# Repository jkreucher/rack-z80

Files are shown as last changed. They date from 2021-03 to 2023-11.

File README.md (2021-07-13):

# Rack Z80 Computer

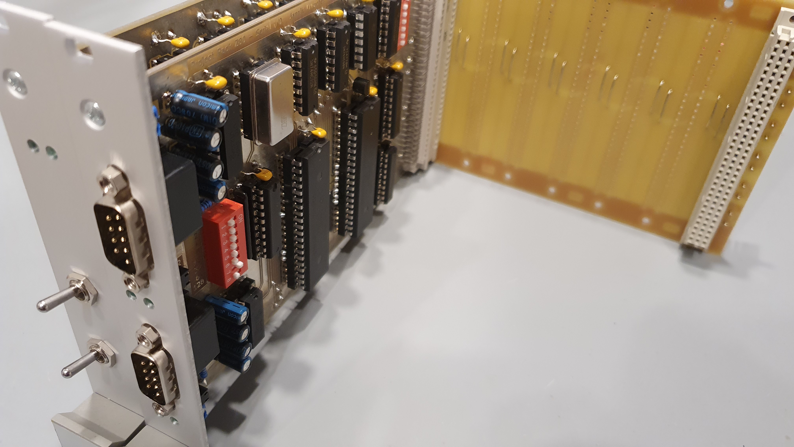
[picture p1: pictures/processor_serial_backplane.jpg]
PCB

Copyright 2021 Jannik Kreucher

**NOTE: This Project is still work in progress and not working at this point !**

## Table of Contents
 - [About The Project](#about-the-project)
 - [Folder Structure](#folder-structure)
 - [Modules](#modules)

## About The Project

The goal of this project is to understand how computers and operating systems work. This is a collection of hardware and software to create a multi purpose 8-Bit computer with the popular [ZiLog Z80](https://de.wikipedia.org/wiki/Zilog_Z80) processor as the heart of this project. Everything is contained in a [Eurocard Subrack](https://en.wikipedia.org/wiki/Eurocard_(printed_circuit_board)) formfactor because I really like the industrial look to it. This makes it really flexible and easy to expand (and good looking of course). All the parts used should still be manufacured and every PCB is etched at home so everyone can reproduce this project. I know chinese PCB houses are fairly cheap these days but I love tinkering and I have the PCB right away and dont need to wait 2 weeks for the next revision because it seems like the first design is never working.

## Folder Structure

The project is divided into following directories:
 - code
 - schematics
 - tools

[`schematics/`](schematics) contains all the PCBs I designed for this project. Each board has its own README file for way more detailed information. [`code/`](code) contains the source code for the Z80 computer itself. The directory [`tools/`](tools) contains everything needed to compile, assemble source code and other software for this project.

## Modules
To get more information about one module click on the link.
 - [Processor Board](schematics/RackZ80_Processor)
 - [RS232 Serial Interface](schematics/RackZ80_RS232)

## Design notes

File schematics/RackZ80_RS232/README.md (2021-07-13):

# Serial I/O

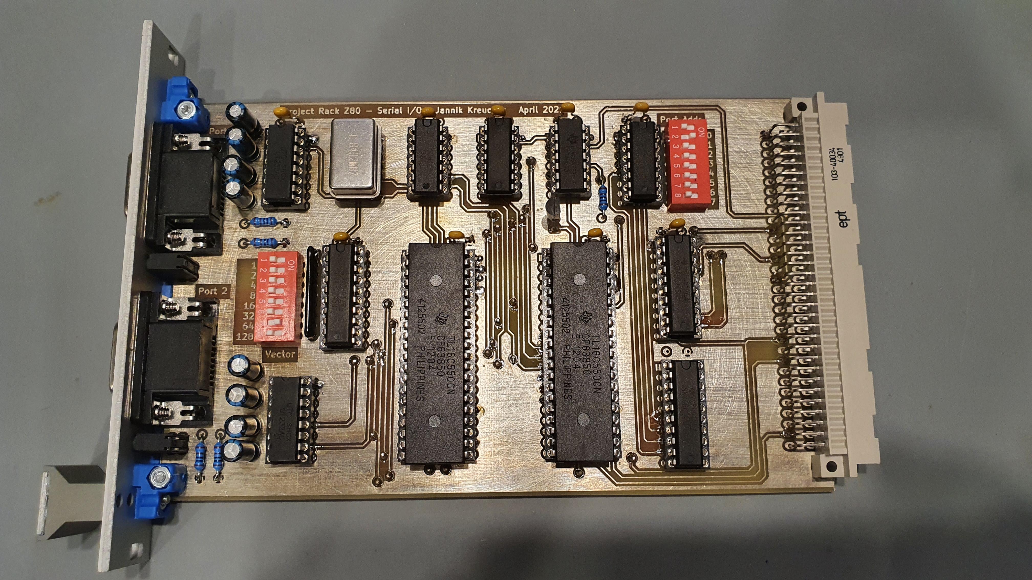
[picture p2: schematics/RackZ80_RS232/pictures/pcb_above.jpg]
PCB

Copyright 2021 Jannik Kreucher

## Table of Contents
 - [How it works](#how-it-works)
 - [Schematic](#schematic)

## How it works
TODO

## Schematic
The [schematic](documentation/RackZ80_RS232.pdf) exported as pdf. So it is ready to print.

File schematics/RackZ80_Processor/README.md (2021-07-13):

# Processor Board

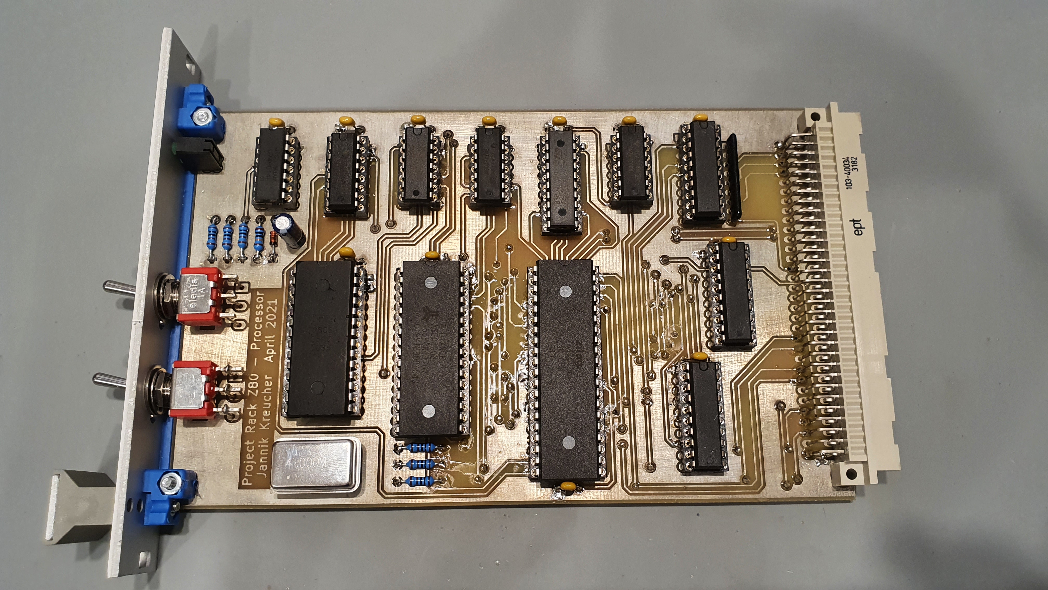
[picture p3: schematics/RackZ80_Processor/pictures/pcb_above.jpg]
PCB

Copyright 2021 Jannik Kreucher

## Table of Contents
 - [How it works](#how-it-works)
 - [Schematic](#schematic)

## How it works
TODO

## Schematic
The [schematic](documentation/RackZ80_Processor.pdf) exported as pdf. So it is ready to print.

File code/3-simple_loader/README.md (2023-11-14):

# Very Simple Loader
This projects aims to make development easier. Removing the EEPROM and programming it every time is very tedious and time consuming. With this project a very simple rom loader is implemented. A binary file can be transferred via UART and be executed by the RackZ80.

## Inner Workings
The CPU expects binary data in form of hex values in ascii on UART port 1. This data gets copied to RAM page 0 which will be placed in the lower 32k later. Once copied, a very simple programm is placed in the upper 32k in RAM page 1 which will replace the lower 32k ROM with the RAM page 0. Next the programm jumps to 0x0000.

Note: No error checking is implemented!

## Sending a Binary File
```
./send.sh ../1-uart_test/uart_echo.rom
```

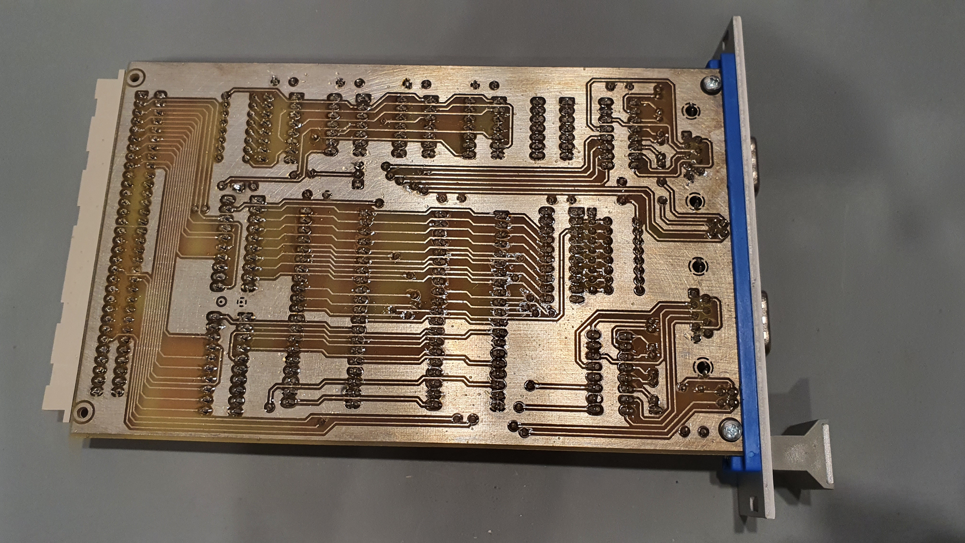
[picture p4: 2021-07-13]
schematics/RackZ80_RS232/pictures/pcb_below.jpg

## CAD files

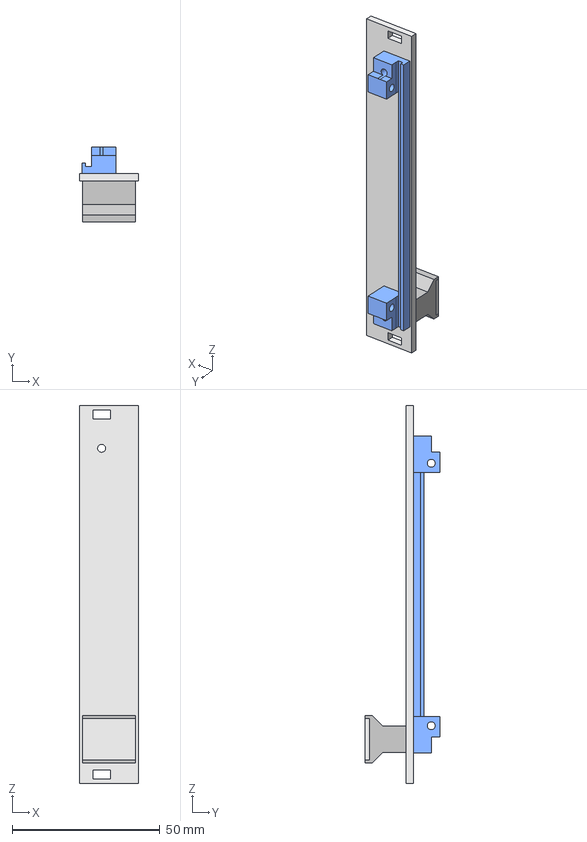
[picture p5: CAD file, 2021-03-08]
schematics/RackZ80_Backplane/rackz80_packages3d/Subrack4TE_FrontPanel.FCStd
20.0 x 25.5 x 128.0 mm
FrontPlate
Handle
NamePlate
PCBMountingSpacer

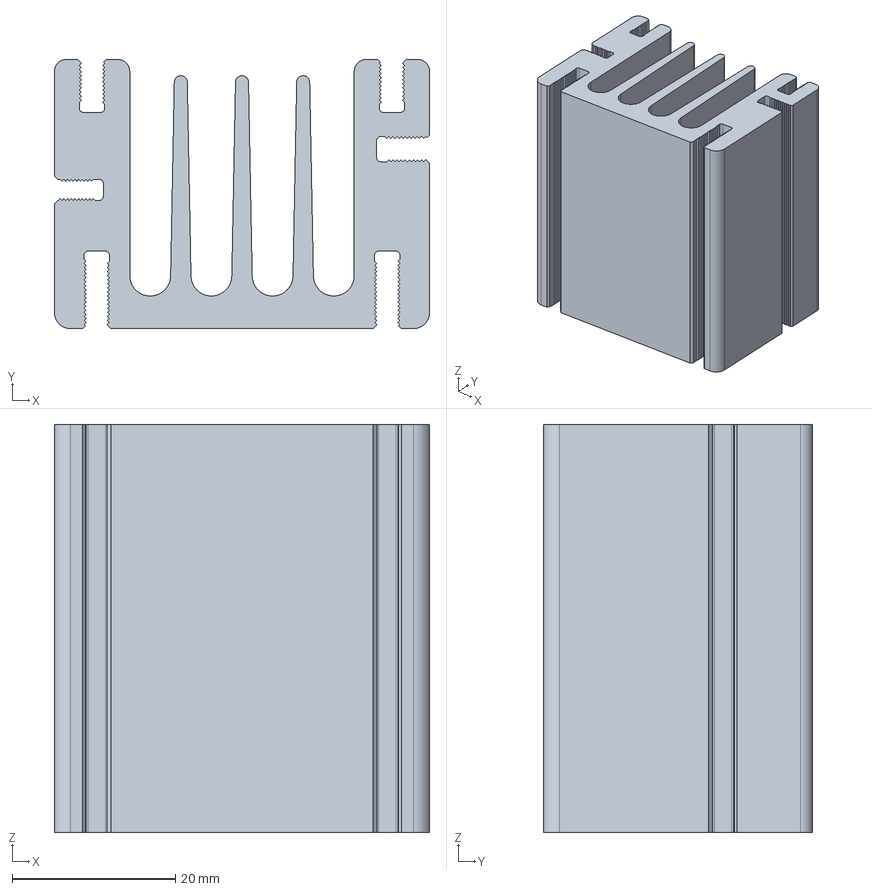
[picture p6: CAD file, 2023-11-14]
schematics/RackZ80_PowerSupply/3dmodels/Fischer_Heatsink_SK68_50mm.step
46.0 x 33.0 x 50.0 mm

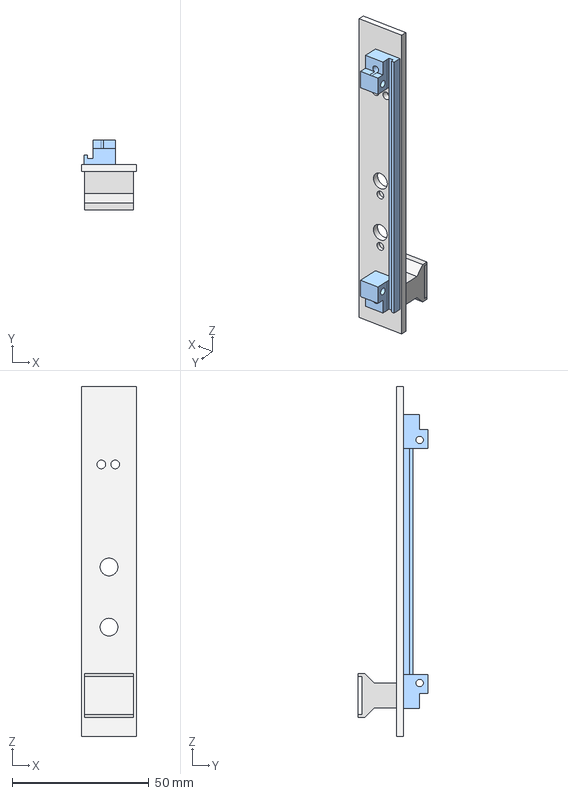
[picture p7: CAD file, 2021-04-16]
schematics/RackZ80_Processor/frontpanel/Subrack4TE_Processor_FrontPanel.step
20.0 x 25.5 x 128.0 mm
Handle
NamePlate
PCBMountingSpacer
ProcessorFrontPanel

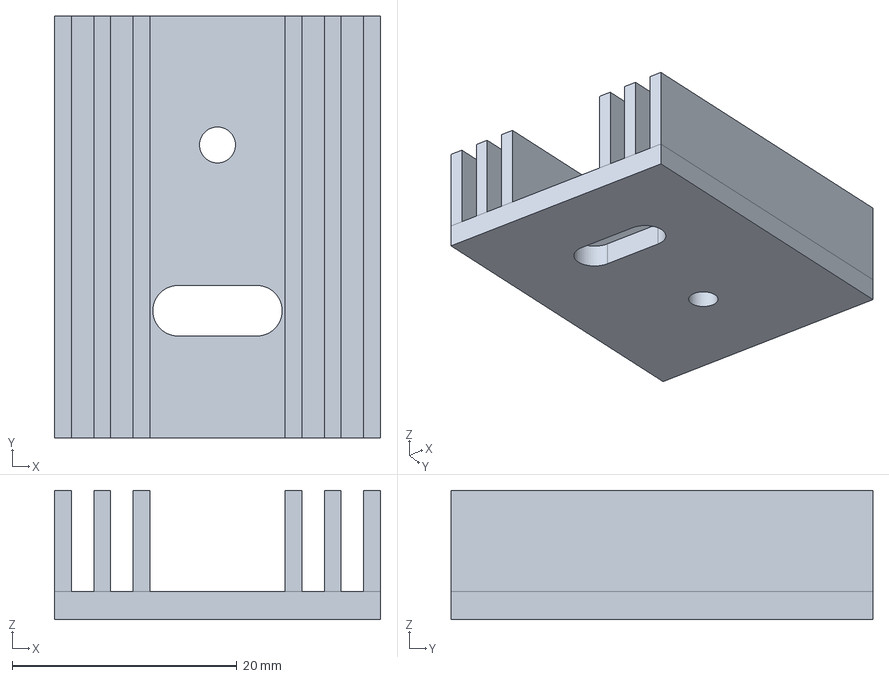
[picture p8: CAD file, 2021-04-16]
schematics/RackZ80_Processor/rackz80_packages3d/SK09_37.FCStd
29.0 x 37.5 x 11.5 mm

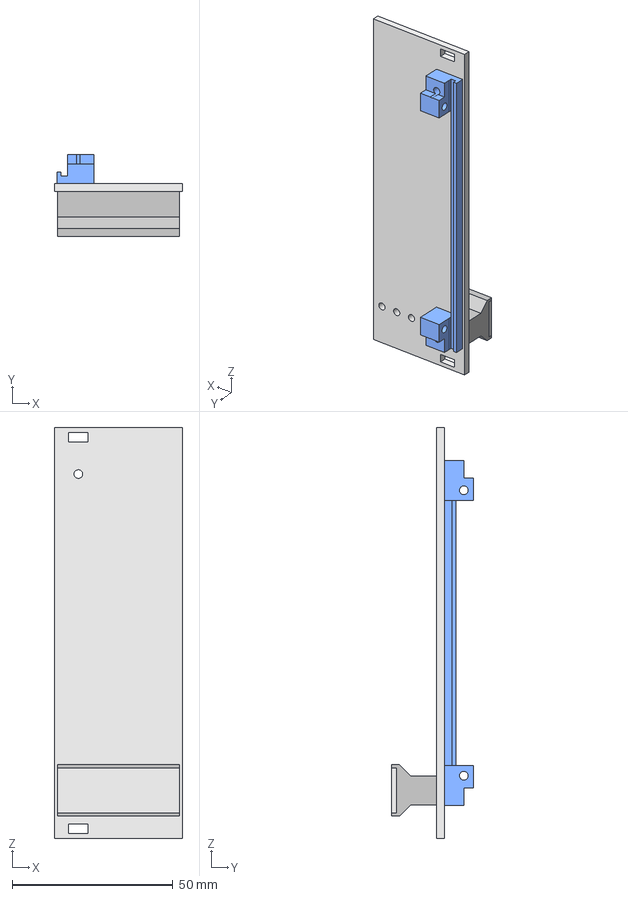
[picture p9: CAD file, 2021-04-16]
schematics/RackZ80_RS232/rackz80_packages3d/Subrack8TE_FrontPanel.FCStd
40.0 x 25.5 x 128.0 mm
FrontPlate
Handle
NamePlate
PCBMountingSpacer

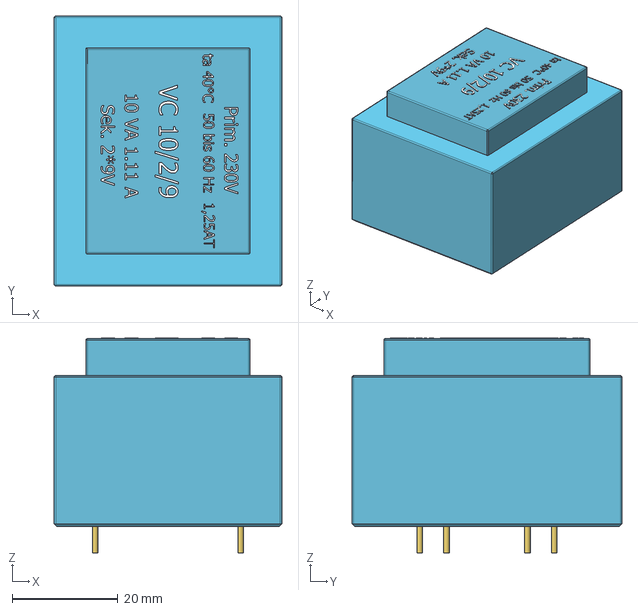
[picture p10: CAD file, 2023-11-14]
schematics/RackZ80_PowerSupply/3dmodels/BlockTrafo_VC10_10VA.step
43.0 x 51.0 x 40.6 mm

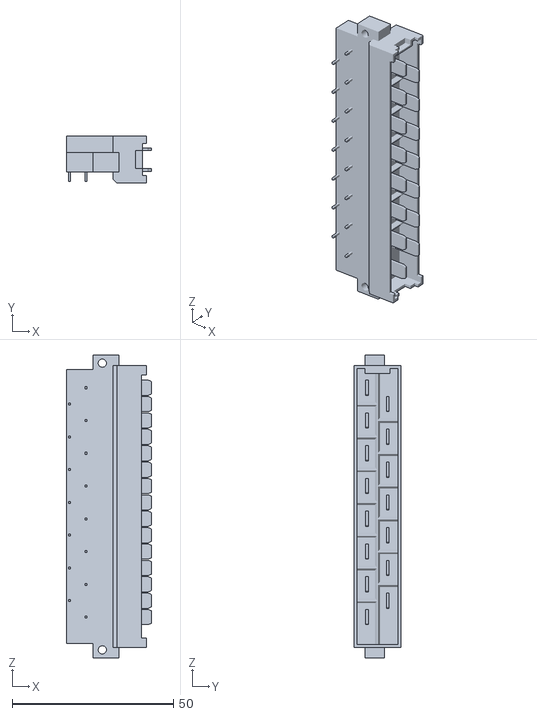
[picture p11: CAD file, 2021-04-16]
schematics/RackZ80_RS232/rackz80_packages3d/User Library-DIN41612-H-15-M-RA.stl
26.4 x 14.7 x 94.0

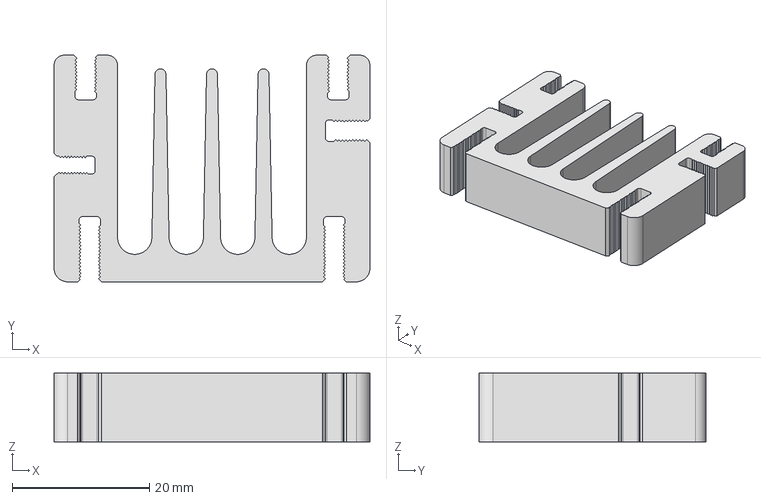
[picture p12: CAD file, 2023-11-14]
schematics/RackZ80_PowerSupply/3dmodels/Fischer_Heatsink_SK68.step
46.0 x 33.0 x 10.0 mm

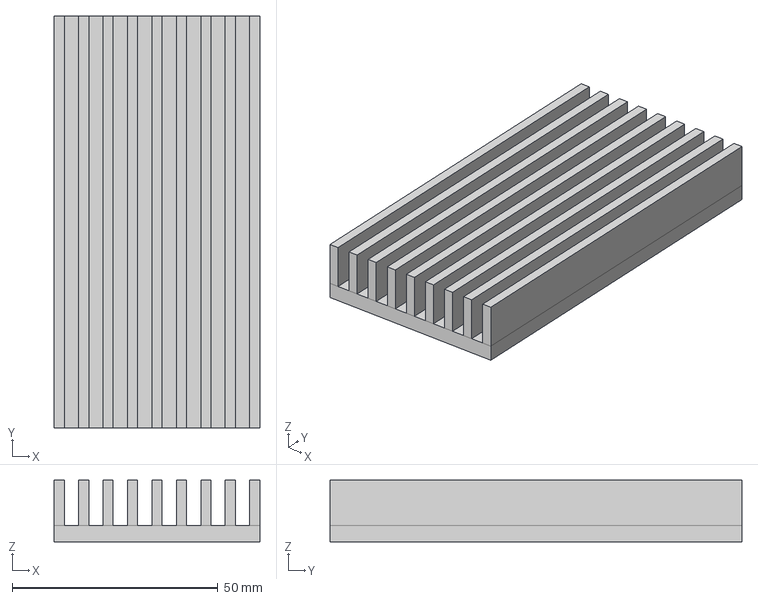
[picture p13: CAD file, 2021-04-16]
schematics/RackZ80_Processor/rackz80_packages3d/Heatsink_SK81_100_Cut.step
50.0 x 100.0 x 15.0 mm

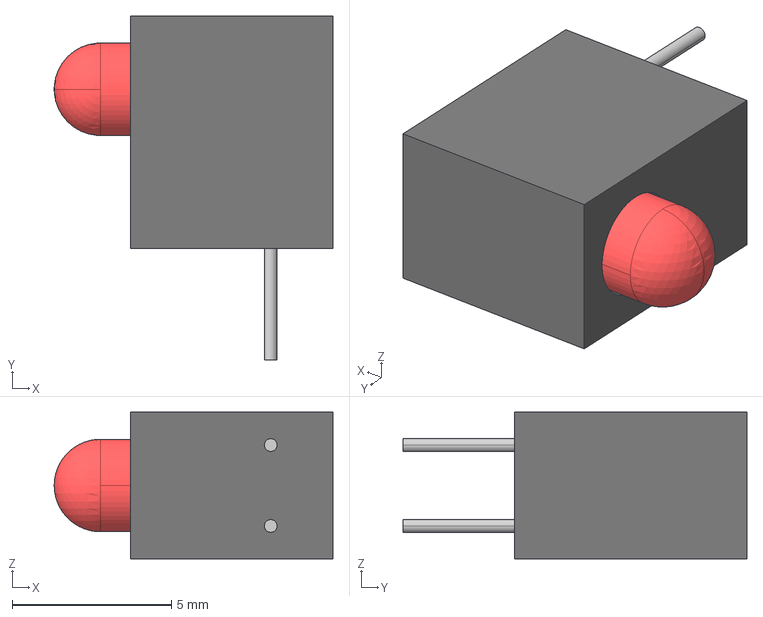
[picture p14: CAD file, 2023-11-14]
schematics/RackZ80_PowerSupply/3dmodels/LED_Kingbright_T-1_3mm_single.step
8.75 x 10.8 x 4.60 mm

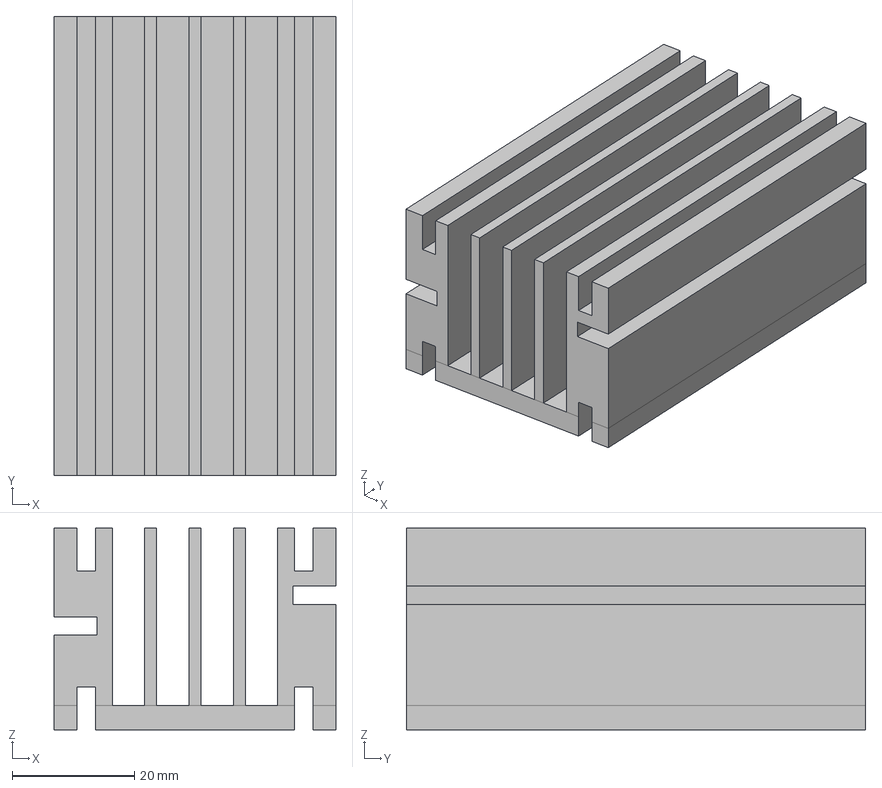
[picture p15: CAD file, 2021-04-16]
schematics/RackZ80_Processor/rackz80_packages3d/SK68_75mm.step
46.0 x 75.0 x 33.0 mm

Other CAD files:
schematics/RackZ80_RS232/frontpanel/Subrack4TE_Serial_FrontPanel.step
schematics/RackZ80_PowerSupply/3dmodels/Fischer_Heatsink_SK68_75mm.step
schematics/RackZ80_PowerSupply/3dmodels/DIN41612_H15_Male_90deg_ept.step
schematics/RackZ80_PowerSupply/3dmodels/Fischer_4TE.step
schematics/RackZ80_PowerSupply/3dmodels/Fischer_8TE.step
schematics/RackZ80_PowerSupply/3dmodels/LED_Kingbright_T-1_3mm_dual.step
schematics/RackZ80_Processor/frontpanel/Subrack4TE_Processor_FrontPanel.FCStd
schematics/RackZ80_Processor/rackz80_packages3d/DIN41612_H15.step
schematics/RackZ80_Processor/rackz80_packages3d/Heatsink_SK81_100_Cut.FCStd
schematics/RackZ80_Processor/rackz80_packages3d/SK09_37-SK09_37.step
schematics/RackZ80_Processor/rackz80_packages3d/SK68_75mm.FCStd
schematics/RackZ80_Processor/rackz80_packages3d/Transformer_30VA_2x12V.step
schematics/RackZ80_Processor/rackz80_packages3d/din41612_H15.step
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

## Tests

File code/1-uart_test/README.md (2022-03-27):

# First UART Test
First UART RX/TX test using vector interrupts. This test code sends characters back it receives using an interrupt. The goal of this simple code is to demonstrate that the cpu and uart boards are working including the Z80 vectored interrupt logic I implemented into the UART card.

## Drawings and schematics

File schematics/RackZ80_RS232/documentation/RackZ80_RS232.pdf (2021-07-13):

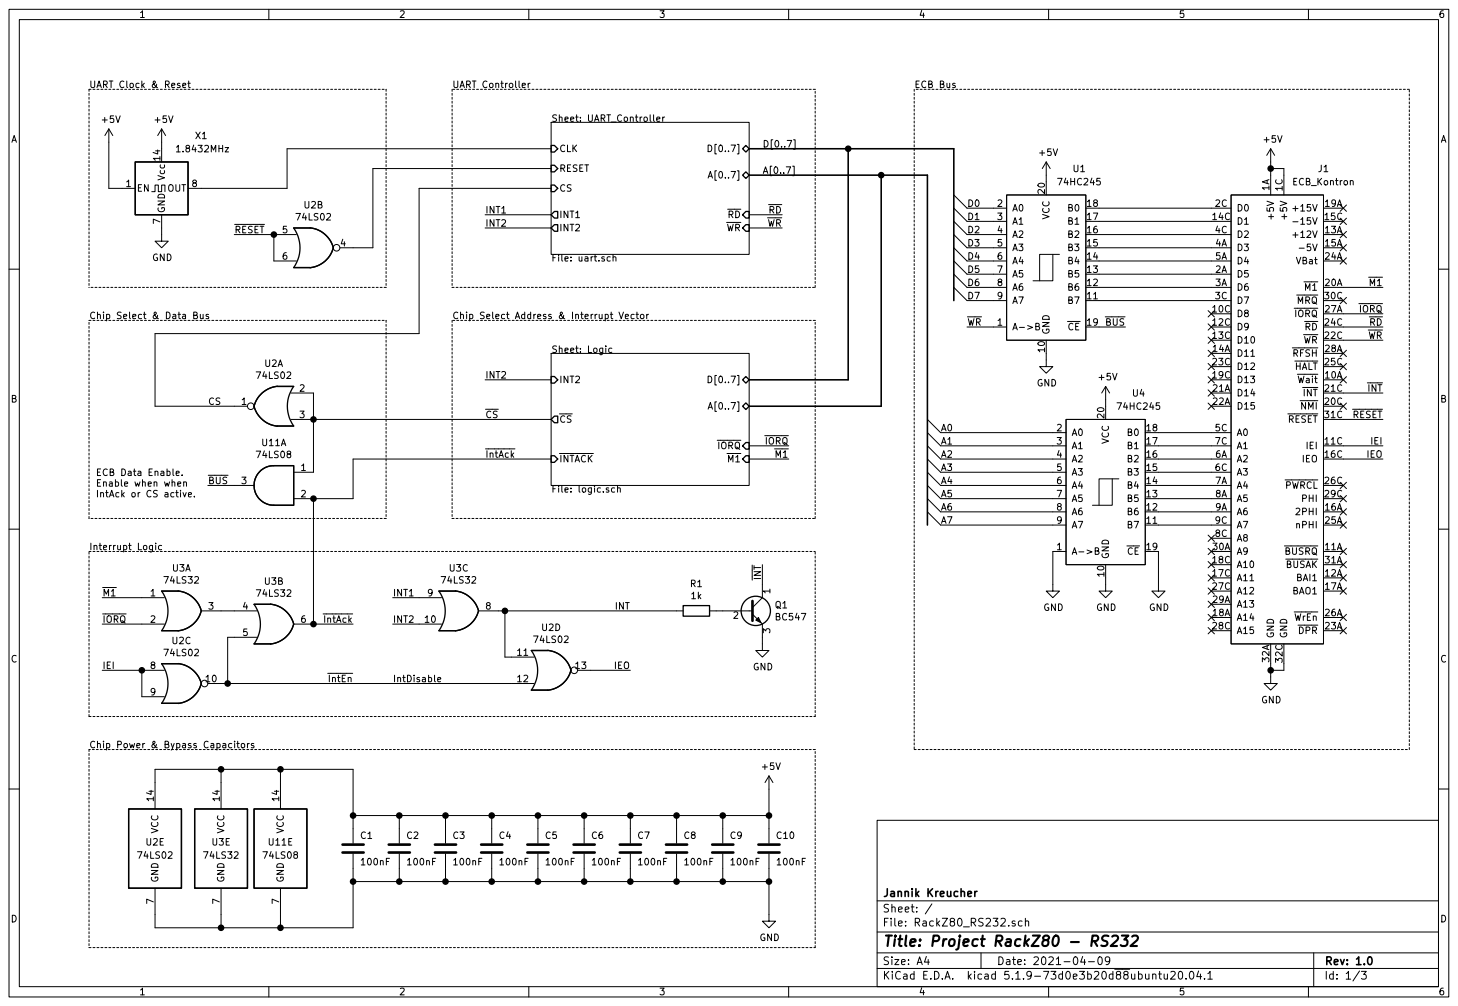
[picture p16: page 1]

IntAck or CS active.

Chip Power & Bypass Capacitors

File: RackZ80_RS232.sch Sheet: / Jannik Kreucher

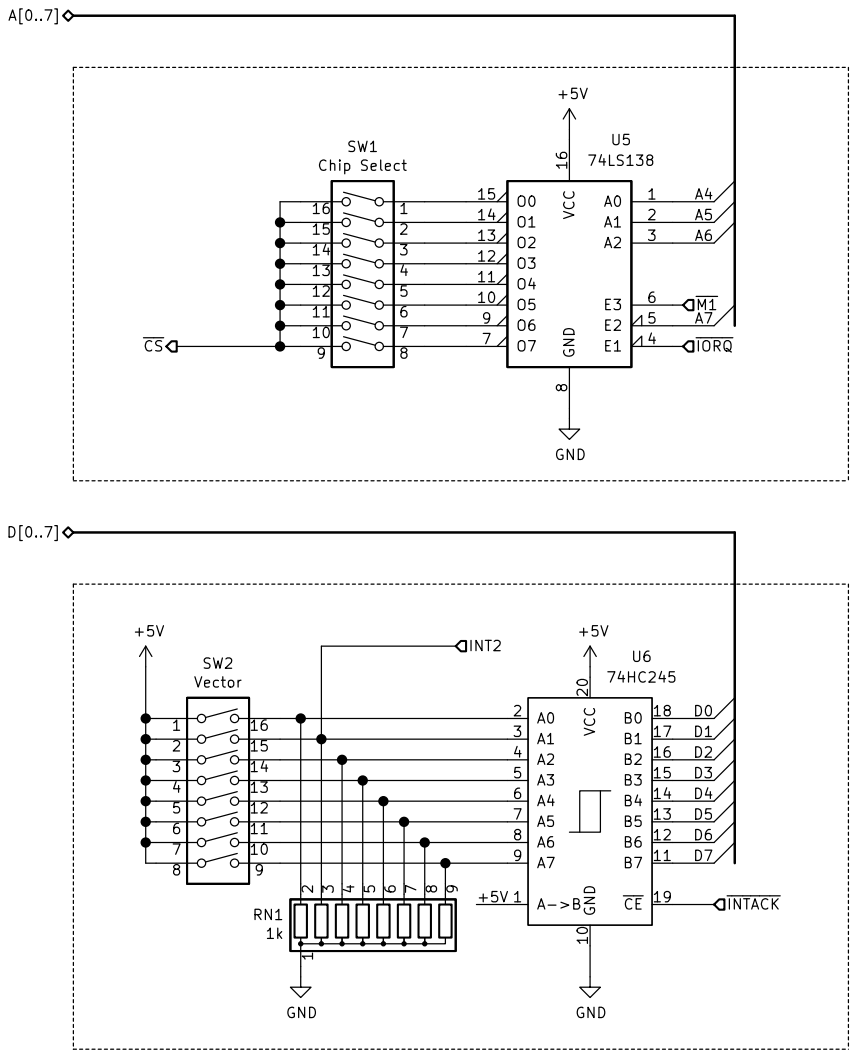
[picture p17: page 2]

16 | 1
15 | 2
14 | 3
13 | 4
12 | 5
11 | 6

16
15
14
13
12
11
10

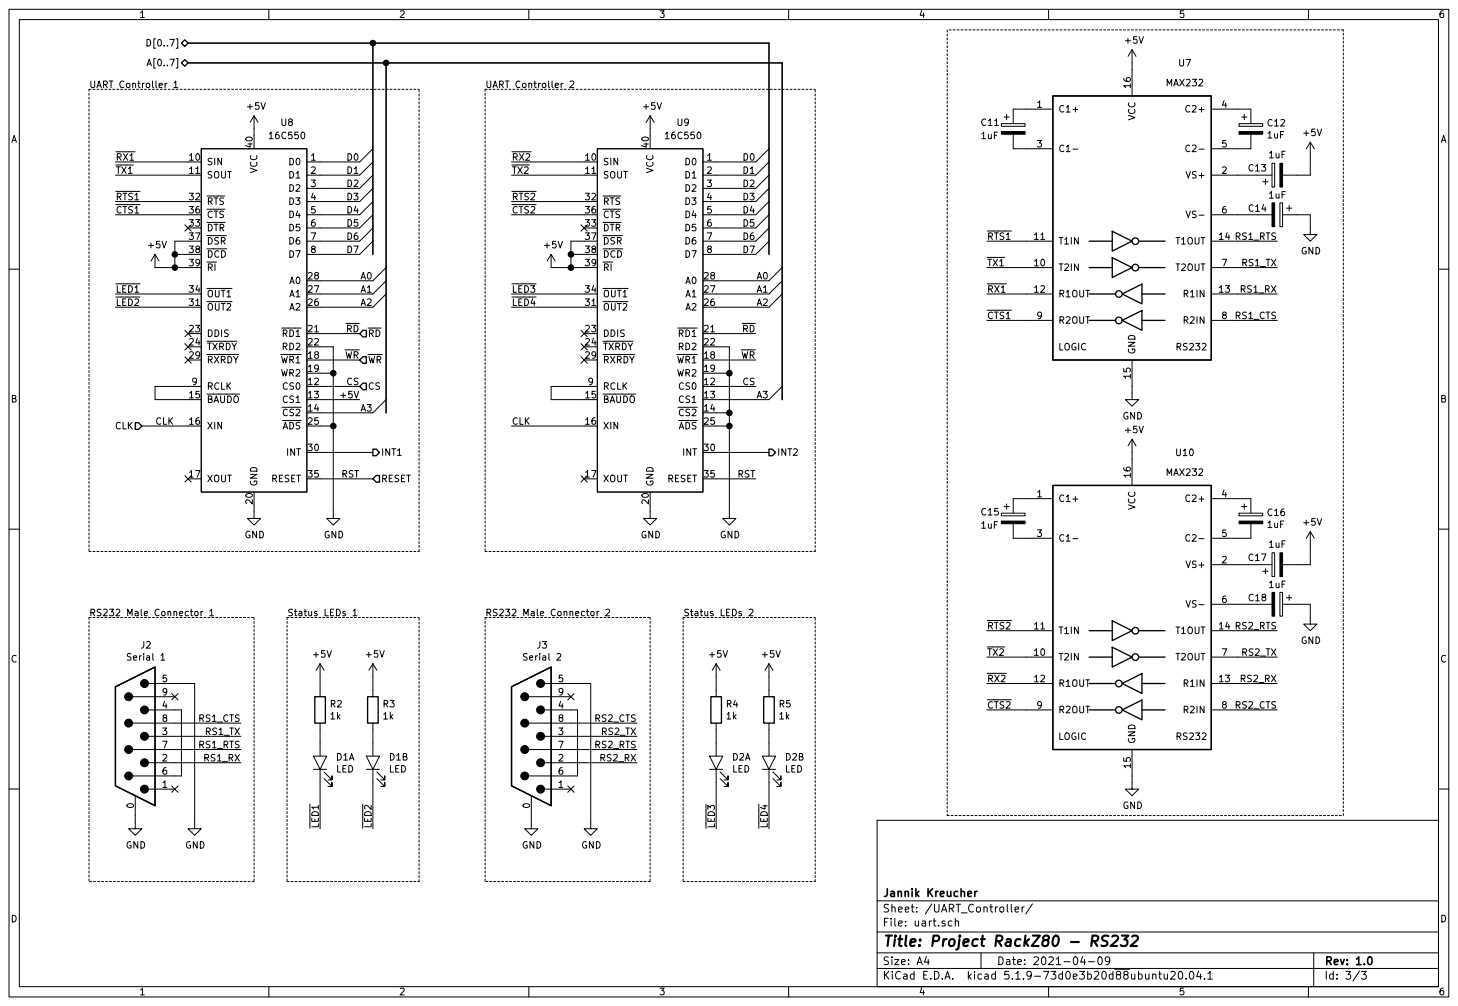
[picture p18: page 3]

UART Controller 2 RS232 Male Connector 2

File: uart.sch Sheet: /UART_Controller/ Jannik Kreucher D2B

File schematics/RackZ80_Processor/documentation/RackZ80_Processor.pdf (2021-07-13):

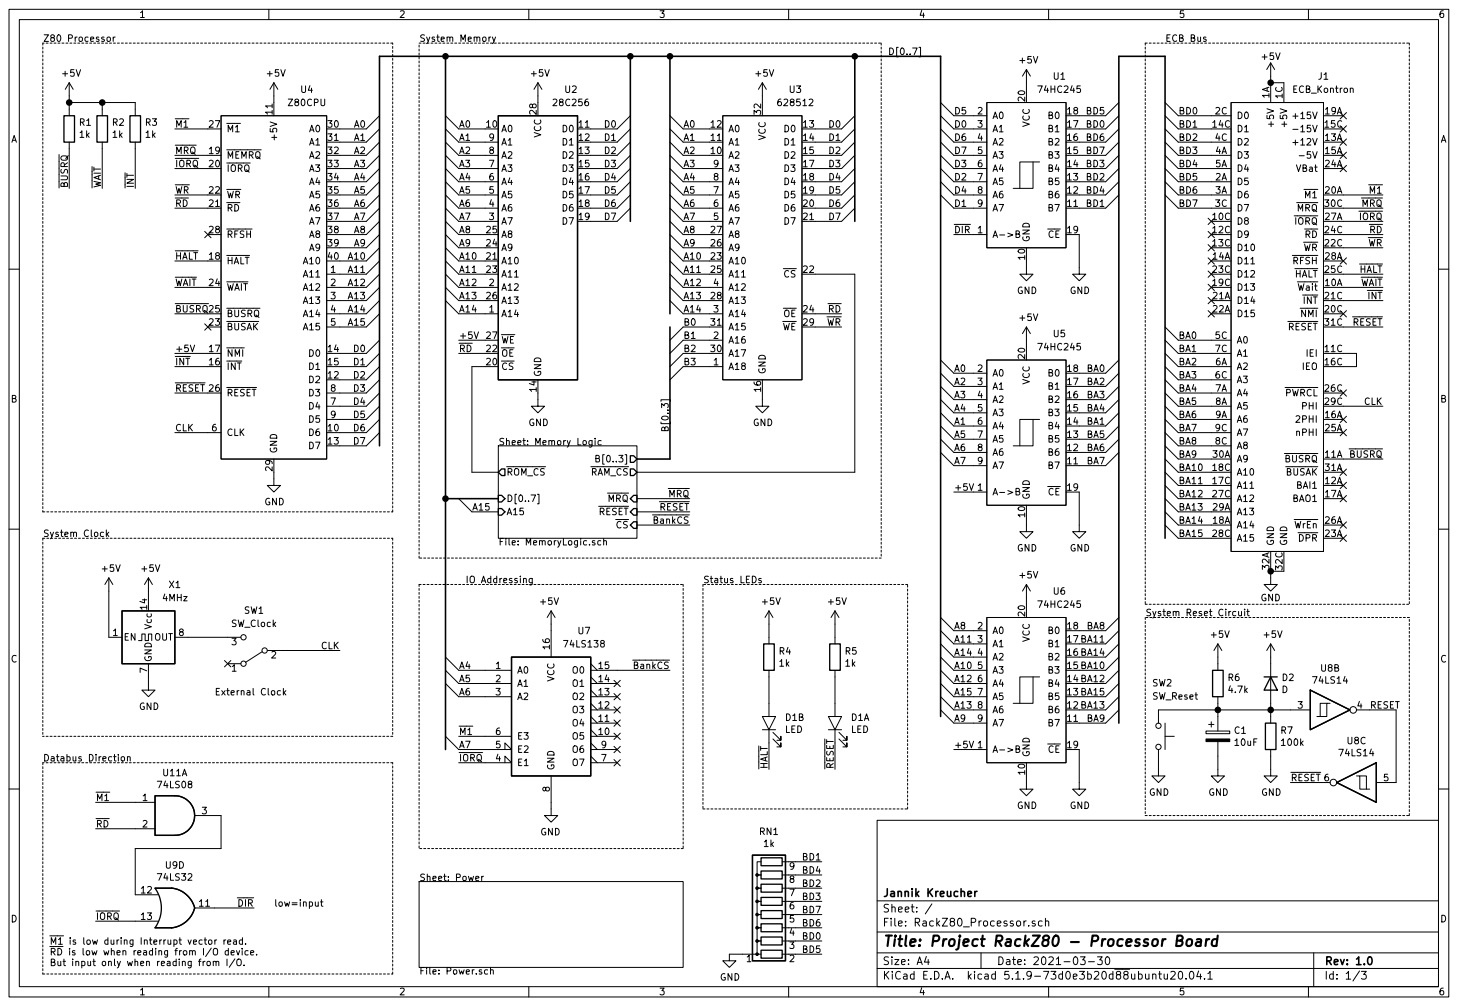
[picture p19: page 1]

File: RackZ80_Processor.sch Sheet: / Jannik Kreucher Sheet: Power File: Power.sch

Id: 1/3 Title: Project RackZ80 - Processor Board

RD is low when reading from I/O device.

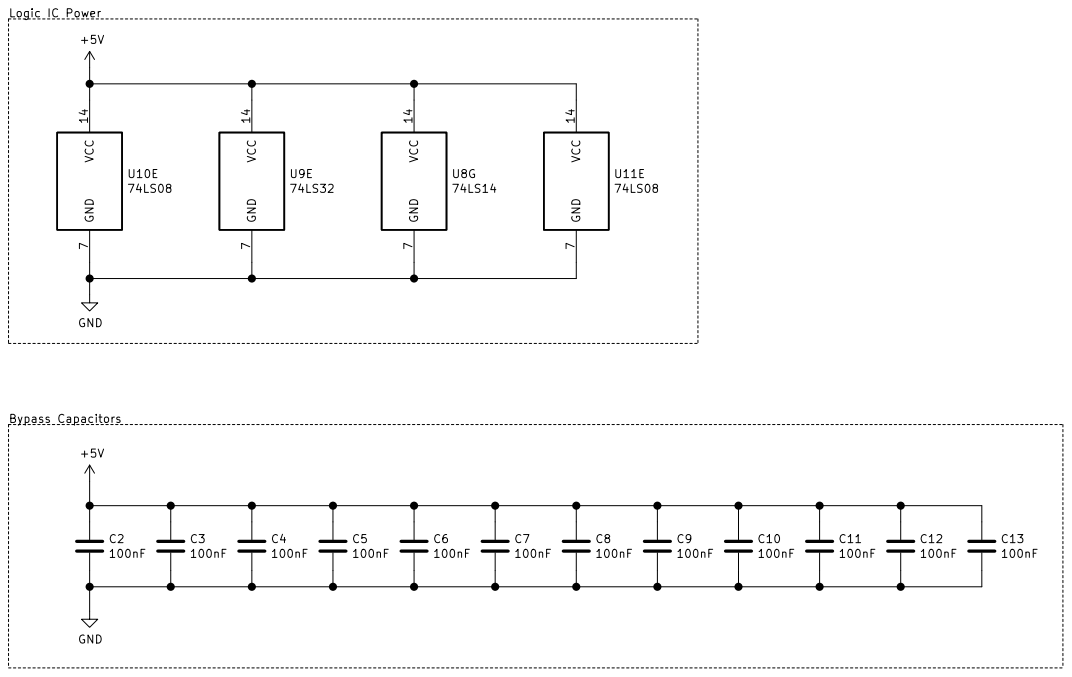
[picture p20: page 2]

Logic IC Power
File: Power.sch Sheet: /Power/ Jannik Kreucher VCC 14 GND

Id: 2/3 Title: Project RackZ80 - Processor Board

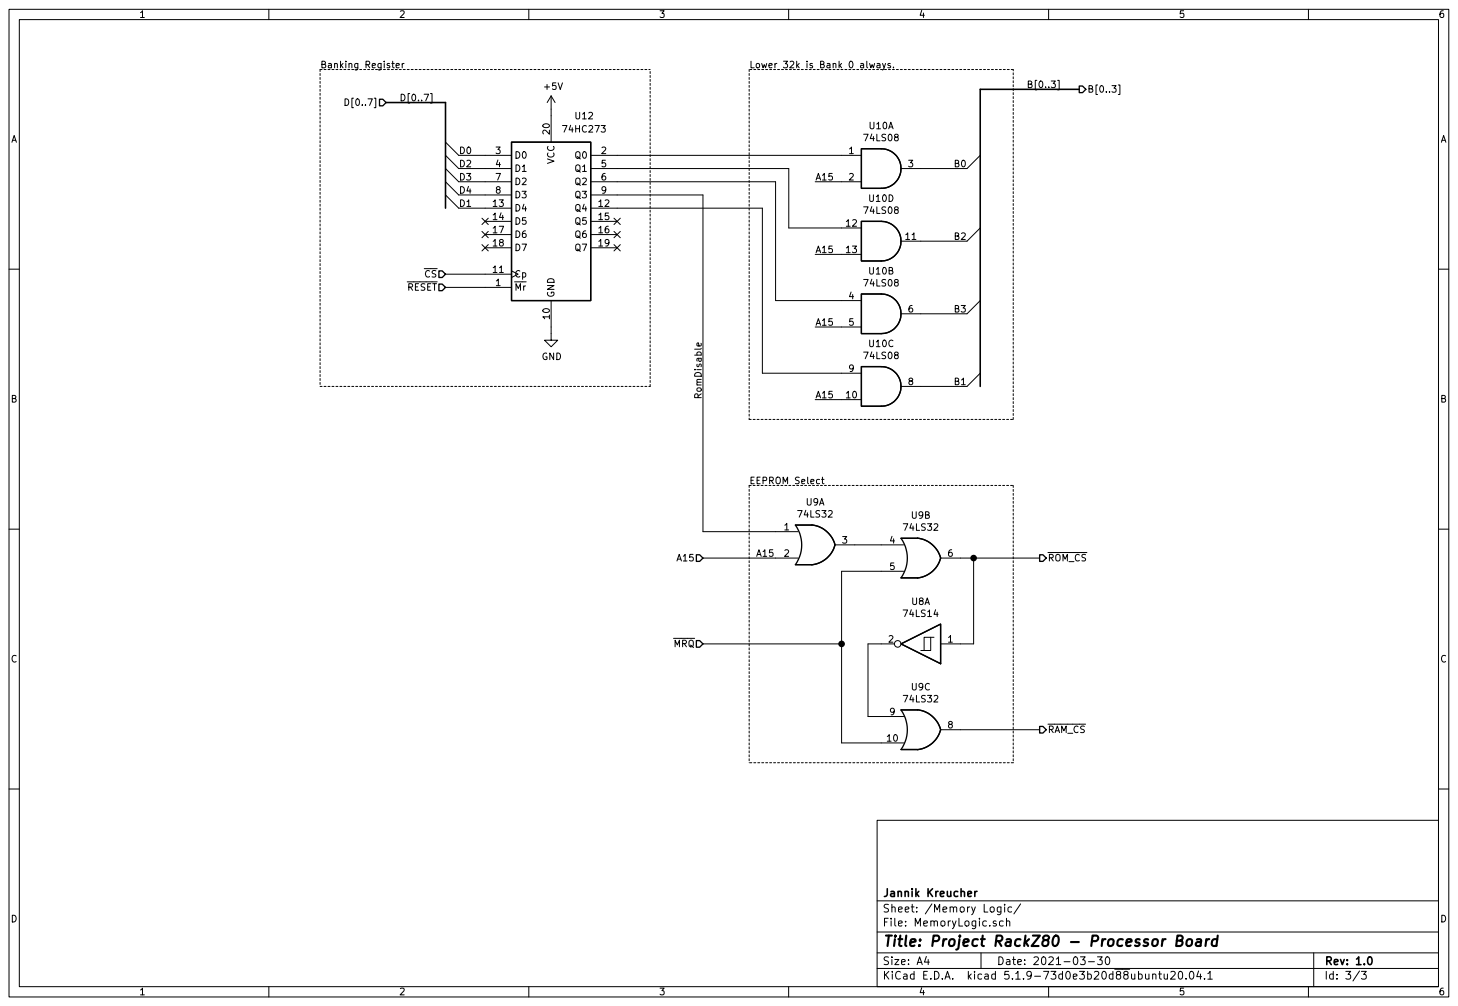
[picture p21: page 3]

Sheet: /Memory Logic/ Jannik Kreucher

File: MemoryLogic.sch
Id: 3/3 Title: Project RackZ80 - Processor Board

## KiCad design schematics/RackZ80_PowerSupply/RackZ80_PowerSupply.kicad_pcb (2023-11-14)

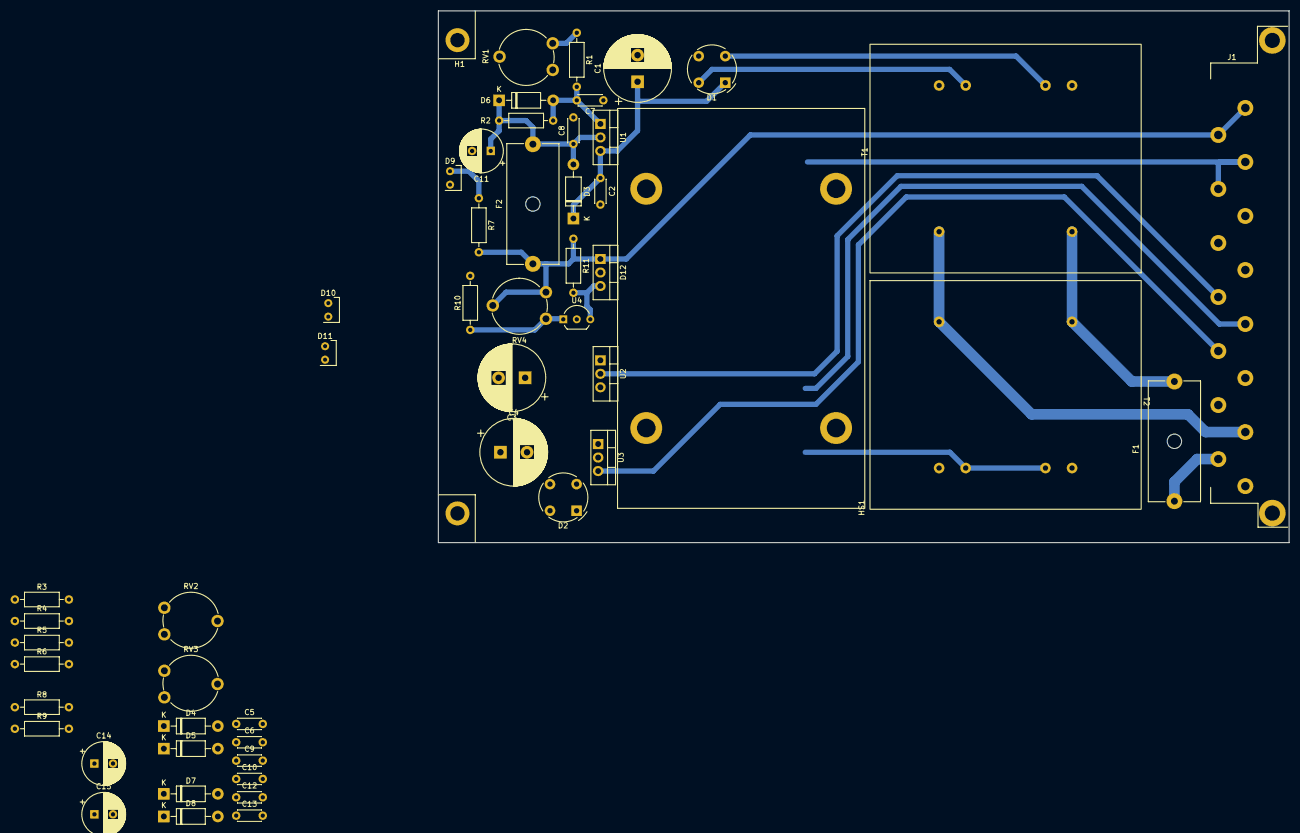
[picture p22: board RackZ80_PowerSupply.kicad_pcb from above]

Board: 2 copper layers, 160.0 x 100.0 mm, 53 parts (0 on the bottom side), 27 nets.

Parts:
C1, C3, C4: 2200u; CP_Radial_D12.5mm_P5.00mm
C2, C5, C6, C7, C8, C9, C10, C12, C13: 100n; C_Disc_D4.3mm_W1.9mm_P5.00mm
C11, C14, C15: 470u; CP_Radial_D8.0mm_P3.50mm
D1, D2: D_Bridge_+A-A; Diode_Bridge_Round_D9.0mm
D3, D4, D5, D6, D7, D8: 1N4002; D_DO-41_SOD81_P10.16mm_Horizontal
D9, D10, D11: LED; LED_Kingbright_T-1_3mm
D12: BT138; TO-220-3_Vertical
F1: 100mA Slow; Fuseholder_Cylinder-5x20mm_Schurter_0031_8201_Horizontal_Op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
F2: 1A Fast; Fuseholder_Cylinder-5x20mm_Schurter_0031_8201_Horizontal_Op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
H1: FrontPanel; Eurocard_FrontPanel
HS1: Heatsink; Heatsink_Fischer_SK68_75mm
J1: DIN41612 H15; DIN41612_H_right_angle
R1, R8, R9: 1k; R_Axial_DIN0207_L6.3mm_D2.5mm_P10.16mm_Horizontal
R2, R10: 470R; R_Axial_DIN0207_L6.3mm_D2.5mm_P10.16mm_Horizontal
R3, R4: 1k8; R_Axial_DIN0207_L6.3mm_D2.5mm_P10.16mm_Horizontal
R5, R6, R7, R11: 240R; R_Axial_DIN0207_L6.3mm_D2.5mm_P10.16mm_Horizontal
RV1, RV2, RV3, RV4: 1k; Potentiometer_Piher_PT-10-V10_Vertical
T1: Transformer_1P_1S; BlockTrafo_10VA
T2: Transformer_1P_2S; BlockTrafo_10VA
U1, U2: LM317_TO-220; TO-220-3_Vertical
U3: LM337_TO220; TO-220-3_Vertical
U4: TL431; TO-92_Inline_Wide

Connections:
+5V: D12.1 (A1), F2.2, J1.4, J1.6, R7.2, R11.1, RV4.1, RV4.2
+15V: C12.1, C14.1, D4.2 (A), D7.1 (K), J1.18, R5.2, R8.1, U2.2 (VO)
-15V: C13.2, C15.2, D5.1 (K), D8.2 (A), J1.22, R6.1, R9.1, U3.3 (VO)
/L: F1.1, J1.30
/N: J1.28, T1.6 (AB), T2.1 (AA)
GND1: C1.2, C2.2, C7.2, C8.2, C11.2, D1.3 (-), D9.1 (K), D12.2 (A2), J1.8, J1.10, R10.2, RV1.2, RV1.3, U4.2 (A)
GND2: C3.2, C4.1, C5.2, C6.1, C9.2, C10.1, C12.2, C13.1, C14.2, C15.1, D10.1 (K), D11.2 (A), J1.20, RV2.2, RV2.3, RV3.1, RV3.2, T2.8 (SB), T2.11 (SC)
unnamed: C1.1, C2.1, D1.1 (+), D3.1 (K), U1.3 (VI)
unnamed: C3.1, C5.1, D2.1 (+), D4.1 (K), U2.3 (VI)
unnamed: C4.2, C6.2, D2.3 (-), D5.2 (A), U3.2 (VI)
unnamed: C8.1, C11.1, D3.2 (A), D6.1 (K), F2.1, R2.2, U1.2 (VO)
unnamed: C7.1, D6.2 (A), R1.2, R2.1, U1.1 (ADJ)
unnamed: C9.1, D7.2 (A), R3.2, R5.1, U2.1 (ADJ)
unnamed: C10.2, D8.1 (K), R4.1, R6.2, U3.1 (ADJ)
unnamed: D9.2 (A), R7.1
unnamed: D10.2 (A), R8.2
unnamed: D11.1 (K), R9.2
unnamed: D12.3 (G), R11.2, U4.3 (K)
unnamed: R1.1, RV1.1
unnamed: R3.1, RV2.1
unnamed: R4.2, RV3.3
unnamed: F1.2, T1.1 (AA), T2.6 (AB)
unnamed: D1.4, T1.8 (SA)
unnamed: D1.2, T1.11 (SB)
unnamed: D2.4, T2.7 (SA)
unnamed: D2.2, T2.12 (SD)
unnamed: R10.1, RV4.3, U4.1 (REF)

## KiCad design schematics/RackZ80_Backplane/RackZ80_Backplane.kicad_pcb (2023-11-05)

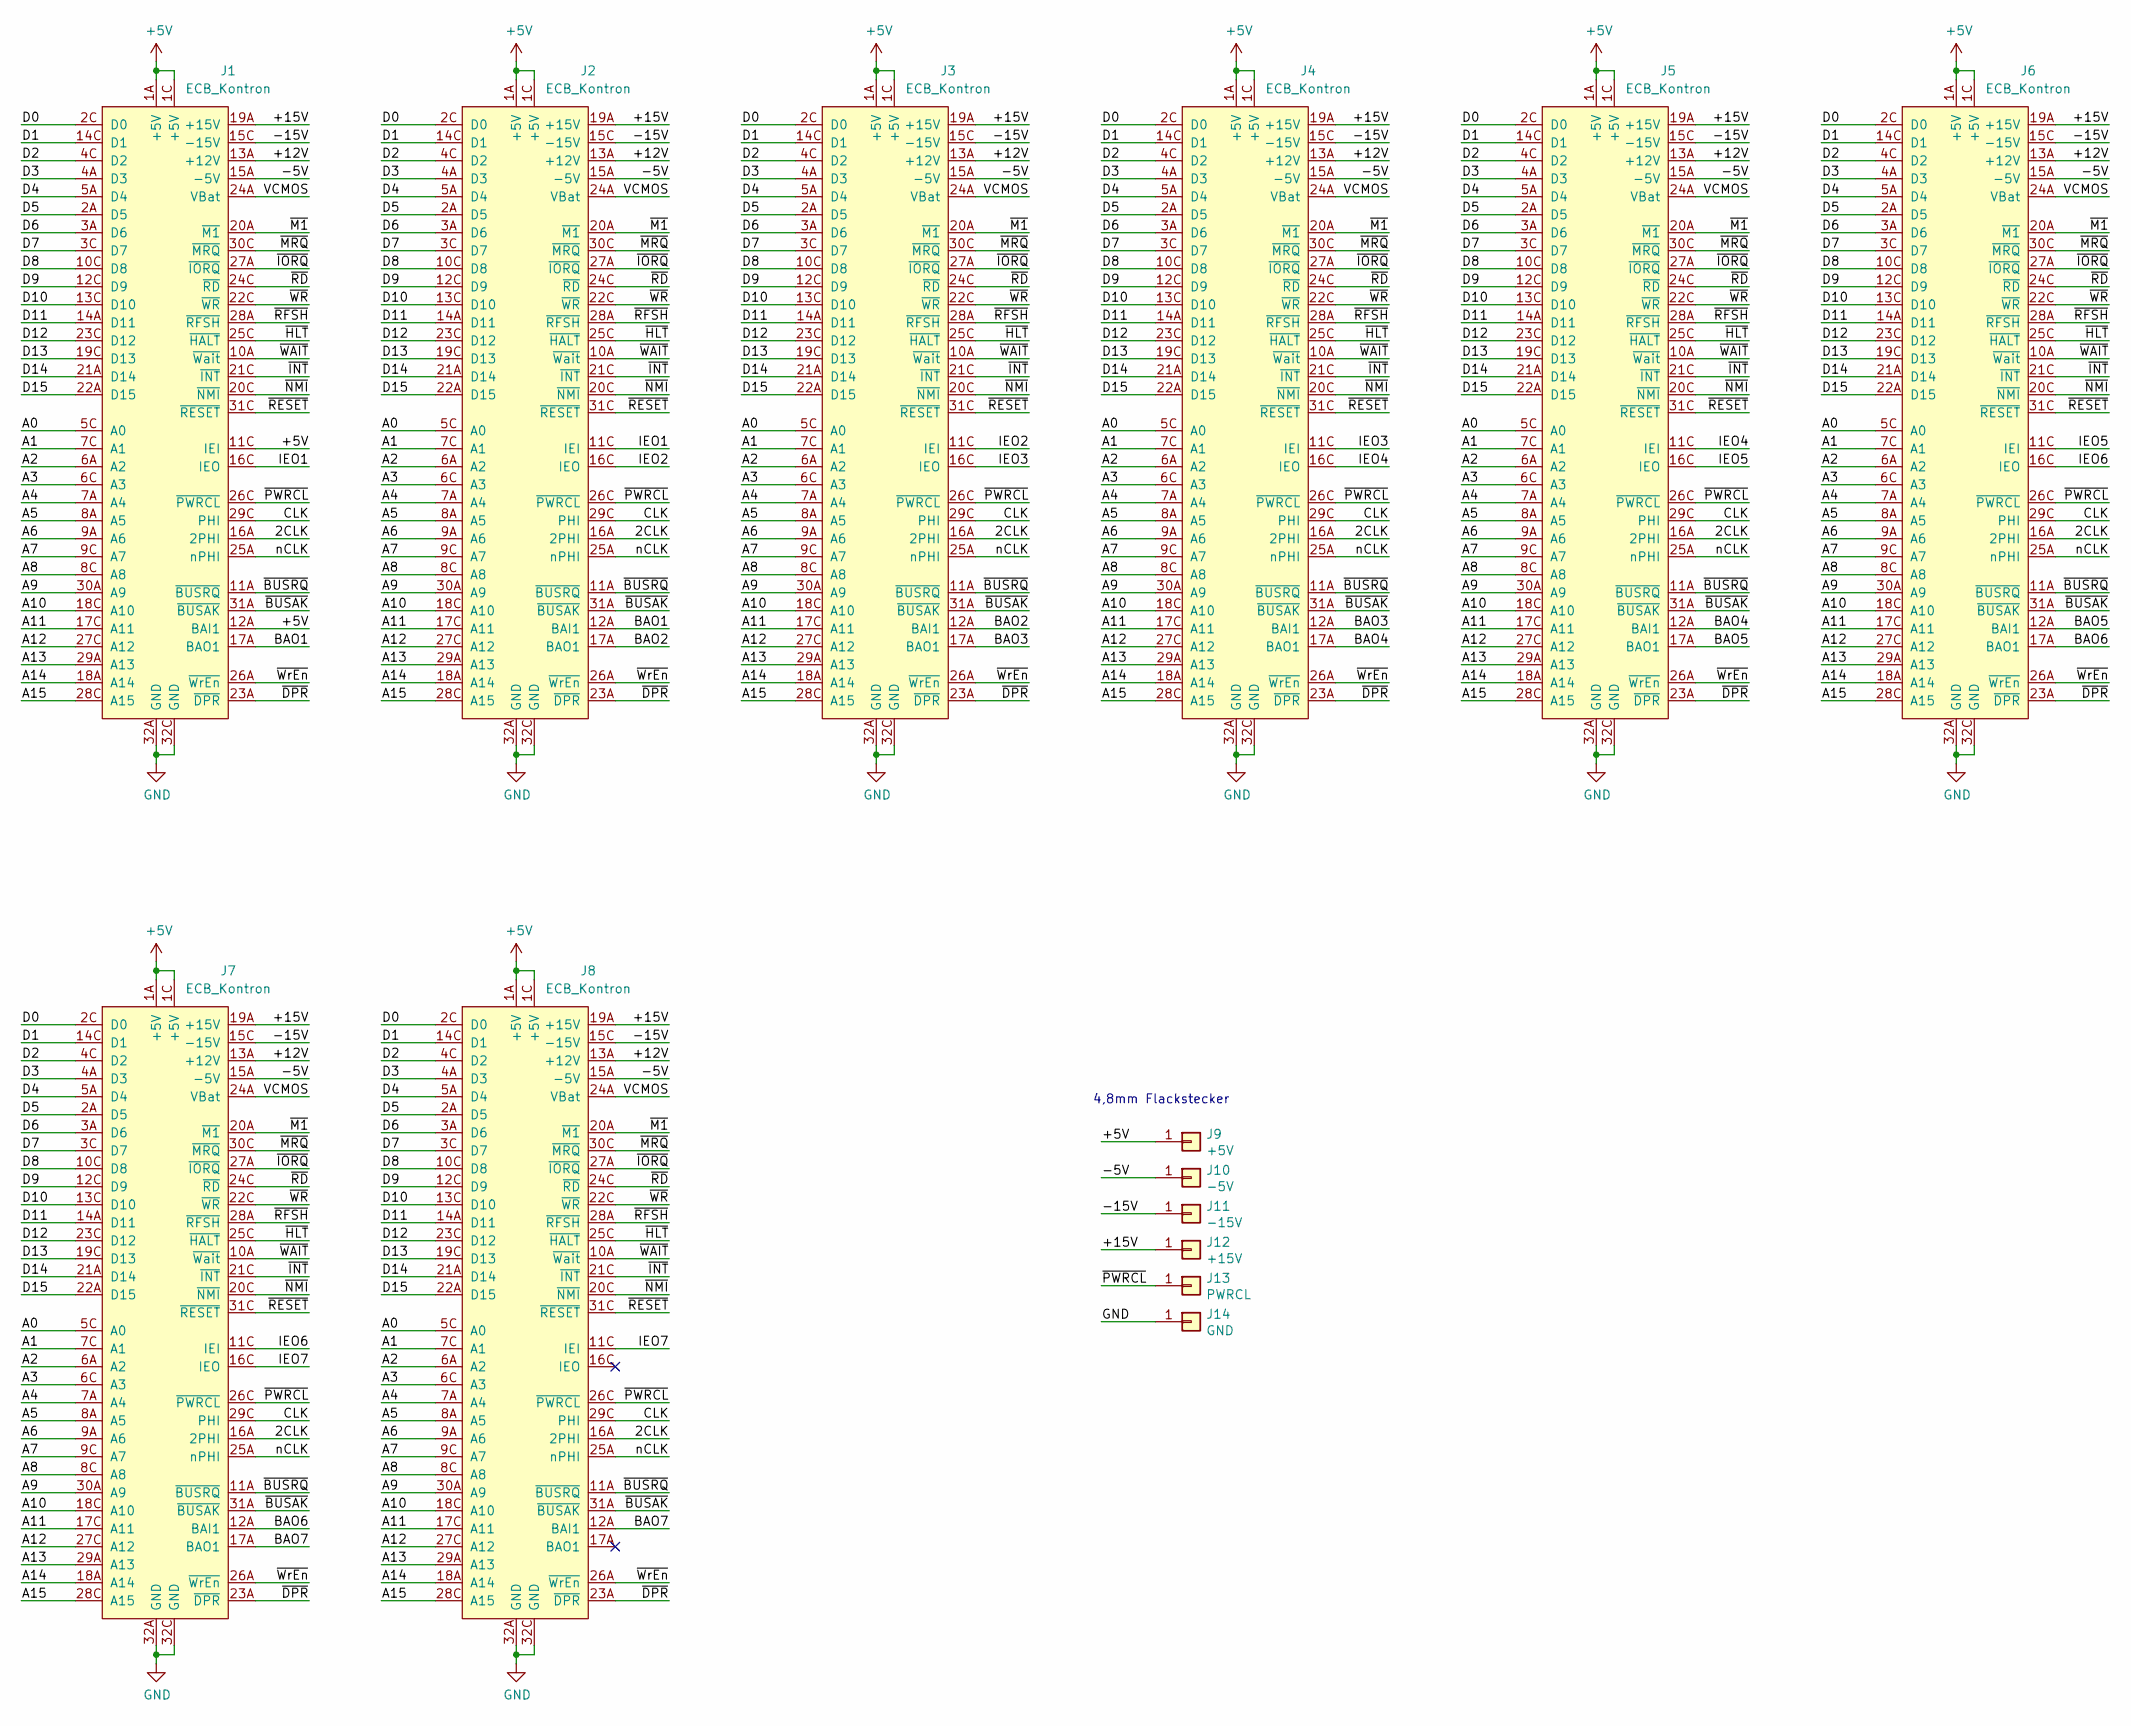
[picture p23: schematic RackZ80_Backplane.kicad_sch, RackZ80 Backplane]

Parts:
J1, J2, J3, J4, J5, J6, J7, J8: ECB_Kontron; Eurocard_DIN41612_C64_Female
J9: +5V; Flat_Spade_Connector_5.0mm
J10: -5V; Flat_Spade_Connector_5.0mm
J11: -15V; Flat_Spade_Connector_5.0mm
J12: +15V; Flat_Spade_Connector_5.0mm
J13: PWRCL; Flat_Spade_Connector_5.0mm
J14: GND; Flat_Spade_Connector_5.0mm

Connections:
+5V: J1.1A (+5V), J1.1C (+5V), J1.11C (IEI), J1.12A (BAI1), J2.1A (+5V), J2.1C (+5V), J3.1A (+5V), J3.1C (+5V), J4.1A (+5V), J4.1C (+5V), J5.1A (+5V), J5.1C (+5V), J6.1A (+5V), J6.1C (+5V), J7.1A (+5V), J7.1C (+5V), J8.1A (+5V), J8.1C (+5V), J9.1
/2CLK: J1.16A (2PHI), J2.16A (2PHI), J3.16A (2PHI), J4.16A (2PHI), J5.16A (2PHI), J6.16A (2PHI), J7.16A (2PHI), J8.16A (2PHI)
/+12V: J1.13A (+12V), J2.13A (+12V), J3.13A (+12V), J4.13A (+12V), J5.13A (+12V), J6.13A (+12V), J7.13A (+12V), J8.13A (+12V)
/+15V: J1.19A (+15V), J2.19A (+15V), J3.19A (+15V), J4.19A (+15V), J5.19A (+15V), J6.19A (+15V), J7.19A (+15V), J8.19A (+15V), J12.1
/-5V: J1.15A (-5V), J2.15A (-5V), J3.15A (-5V), J4.15A (-5V), J5.15A (-5V), J6.15A (-5V), J7.15A (-5V), J8.15A (-5V), J10.1
/-15V: J1.15C (-15V), J2.15C (-15V), J3.15C (-15V), J4.15C (-15V), J5.15C (-15V), J6.15C (-15V), J7.15C (-15V), J8.15C (-15V), J11.1
/A0: J1.5C (A0), J2.5C (A0), J3.5C (A0), J4.5C (A0), J5.5C (A0), J6.5C (A0), J7.5C (A0), J8.5C (A0)
/A1: J1.7C (A1), J2.7C (A1), J3.7C (A1), J4.7C (A1), J5.7C (A1), J6.7C (A1), J7.7C (A1), J8.7C (A1)
/A2: J1.6A (A2), J2.6A (A2), J3.6A (A2), J4.6A (A2), J5.6A (A2), J6.6A (A2), J7.6A (A2), J8.6A (A2)
/A3: J1.6C (A3), J2.6C (A3), J3.6C (A3), J4.6C (A3), J5.6C (A3), J6.6C (A3), J7.6C (A3), J8.6C (A3)
/A4: J1.7A (A4), J2.7A (A4), J3.7A (A4), J4.7A (A4), J5.7A (A4), J6.7A (A4), J7.7A (A4), J8.7A (A4)
/A5: J1.8A (A5), J2.8A (A5), J3.8A (A5), J4.8A (A5), J5.8A (A5), J6.8A (A5), J7.8A (A5), J8.8A (A5)
/A6: J1.9A (A6), J2.9A (A6), J3.9A (A6), J4.9A (A6), J5.9A (A6), J6.9A (A6), J7.9A (A6), J8.9A (A6)
/A7: J1.9C (A7), J2.9C (A7), J3.9C (A7), J4.9C (A7), J5.9C (A7), J6.9C (A7), J7.9C (A7), J8.9C (A7)
/A8: J1.8C (A8), J2.8C (A8), J3.8C (A8), J4.8C (A8), J5.8C (A8), J6.8C (A8), J7.8C (A8), J8.8C (A8)
/A9: J1.30A (A9), J2.30A (A9), J3.30A (A9), J4.30A (A9), J5.30A (A9), J6.30A (A9), J7.30A (A9), J8.30A (A9)
/A10: J1.18C (A10), J2.18C (A10), J3.18C (A10), J4.18C (A10), J5.18C (A10), J6.18C (A10), J7.18C (A10), J8.18C (A10)
/A11: J1.17C (A11), J2.17C (A11), J3.17C (A11), J4.17C (A11), J5.17C (A11), J6.17C (A11), J7.17C (A11), J8.17C (A11)
/A12: J1.27C (A12), J2.27C (A12), J3.27C (A12), J4.27C (A12), J5.27C (A12), J6.27C (A12), J7.27C (A12), J8.27C (A12)
/A13: J1.29A (A13), J2.29A (A13), J3.29A (A13), J4.29A (A13), J5.29A (A13), J6.29A (A13), J7.29A (A13), J8.29A (A13)
/A14: J1.18A (A14), J2.18A (A14), J3.18A (A14), J4.18A (A14), J5.18A (A14), J6.18A (A14), J7.18A (A14), J8.18A (A14)
/A15: J1.28C (A15), J2.28C (A15), J3.28C (A15), J4.28C (A15), J5.28C (A15), J6.28C (A15), J7.28C (A15), J8.28C (A15)
/BAO1: J1.17A (BAO1), J2.12A (BAI1)
/BAO2: J2.17A (BAO1), J3.12A (BAI1)
/BAO3: J3.17A (BAO1), J4.12A (BAI1)
/BAO4: J4.17A (BAO1), J5.12A (BAI1)
/BAO5: J5.17A (BAO1), J6.12A (BAI1)
/BAO6: J6.17A (BAO1), J7.12A (BAI1)
/BAO7: J7.17A (BAO1), J8.12A (BAI1)
/CLK: J1.29C (PHI), J2.29C (PHI), J3.29C (PHI), J4.29C (PHI), J5.29C (PHI), J6.29C (PHI), J7.29C (PHI), J8.29C (PHI)
/D0: J1.2C (D0), J2.2C (D0), J3.2C (D0), J4.2C (D0), J5.2C (D0), J6.2C (D0), J7.2C (D0), J8.2C (D0)
/D1: J1.14C (D1), J2.14C (D1), J3.14C (D1), J4.14C (D1), J5.14C (D1), J6.14C (D1), J7.14C (D1), J8.14C (D1)
/D2: J1.4C (D2), J2.4C (D2), J3.4C (D2), J4.4C (D2), J5.4C (D2), J6.4C (D2), J7.4C (D2), J8.4C (D2)
/D3: J1.4A (D3), J2.4A (D3), J3.4A (D3), J4.4A (D3), J5.4A (D3), J6.4A (D3), J7.4A (D3), J8.4A (D3)
/D4: J1.5A (D4), J2.5A (D4), J3.5A (D4), J4.5A (D4), J5.5A (D4), J6.5A (D4), J7.5A (D4), J8.5A (D4)
/D5: J1.2A (D5), J2.2A (D5), J3.2A (D5), J4.2A (D5), J5.2A (D5), J6.2A (D5), J7.2A (D5), J8.2A (D5)
/D6: J1.3A (D6), J2.3A (D6), J3.3A (D6), J4.3A (D6), J5.3A (D6), J6.3A (D6), J7.3A (D6), J8.3A (D6)
/D7: J1.3C (D7), J2.3C (D7), J3.3C (D7), J4.3C (D7), J5.3C (D7), J6.3C (D7), J7.3C (D7), J8.3C (D7)
/D8: J1.10C (D8), J2.10C (D8), J3.10C (D8), J4.10C (D8), J5.10C (D8), J6.10C (D8), J7.10C (D8), J8.10C (D8)
/D9: J1.12C (D9), J2.12C (D9), J3.12C (D9), J4.12C (D9), J5.12C (D9), J6.12C (D9), J7.12C (D9), J8.12C (D9)
/D10: J1.13C (D10), J2.13C (D10), J3.13C (D10), J4.13C (D10), J5.13C (D10), J6.13C (D10), J7.13C (D10), J8.13C (D10)
/D11: J1.14A (D11), J2.14A (D11), J3.14A (D11), J4.14A (D11), J5.14A (D11), J6.14A (D11), J7.14A (D11), J8.14A (D11)
/D12: J1.23C (D12), J2.23C (D12), J3.23C (D12), J4.23C (D12), J5.23C (D12), J6.23C (D12), J7.23C (D12), J8.23C (D12)
/D13: J1.19C (D13), J2.19C (D13), J3.19C (D13), J4.19C (D13), J5.19C (D13), J6.19C (D13), J7.19C (D13), J8.19C (D13)
/D14: J1.21A (D14), J2.21A (D14), J3.21A (D14), J4.21A (D14), J5.21A (D14), J6.21A (D14), J7.21A (D14), J8.21A (D14)
/D15: J1.22A (D15), J2.22A (D15), J3.22A (D15), J4.22A (D15), J5.22A (D15), J6.22A (D15), J7.22A (D15), J8.22A (D15)
/IEO1: J1.16C (IEO), J2.11C (IEI)
/IEO2: J2.16C (IEO), J3.11C (IEI)
/IEO3: J3.16C (IEO), J4.11C (IEI)
/IEO4: J4.16C (IEO), J5.11C (IEI)
/IEO5: J5.16C (IEO), J6.11C (IEI)
/IEO6: J6.16C (IEO), J7.11C (IEI)
/IEO7: J7.16C (IEO), J8.11C (IEI)
/VCMOS: J1.24A (VBat), J2.24A (VBat), J3.24A (VBat), J4.24A (VBat), J5.24A (VBat), J6.24A (VBat), J7.24A (VBat), J8.24A (VBat)
/nCLK: J1.25A (nPHI), J2.25A (nPHI), J3.25A (nPHI), J4.25A (nPHI), J5.25A (nPHI), J6.25A (nPHI), J7.25A (nPHI), J8.25A (nPHI)
/~BUSAK: J1.31A (~BUSAK), J2.31A (~BUSAK), J3.31A (~BUSAK), J4.31A (~BUSAK), J5.31A (~BUSAK), J6.31A (~BUSAK), J7.31A (~BUSAK), J8.31A (~BUSAK)
/~BUSRQ: J1.11A (~BUSRQ), J2.11A (~BUSRQ), J3.11A (~BUSRQ), J4.11A (~BUSRQ), J5.11A (~BUSRQ), J6.11A (~BUSRQ), J7.11A (~BUSRQ), J8.11A (~BUSRQ)
/~DPR: J1.23A (~DPR), J2.23A (~DPR), J3.23A (~DPR), J4.23A (~DPR), J5.23A (~DPR), J6.23A (~DPR), J7.23A (~DPR), J8.23A (~DPR)
/~HLT: J1.25C (~HALT), J2.25C (~HALT), J3.25C (~HALT), J4.25C (~HALT), J5.25C (~HALT), J6.25C (~HALT), J7.25C (~HALT), J8.25C (~HALT)
/~INT: J1.21C (~INT), J2.21C (~INT), J3.21C (~INT), J4.21C (~INT), J5.21C (~INT), J6.21C (~INT), J7.21C (~INT), J8.21C (~INT)
/~IORQ: J1.27A (~IORQ), J2.27A (~IORQ), J3.27A (~IORQ), J4.27A (~IORQ), J5.27A (~IORQ), J6.27A (~IORQ), J7.27A (~IORQ), J8.27A (~IORQ)
/~M1: J1.20A (~M1), J2.20A (~M1), J3.20A (~M1), J4.20A (~M1), J5.20A (~M1), J6.20A (~M1), J7.20A (~M1), J8.20A (~M1)
/~MRQ: J1.30C (~MRQ), J2.30C (~MRQ), J3.30C (~MRQ), J4.30C (~MRQ), J5.30C (~MRQ), J6.30C (~MRQ), J7.30C (~MRQ), J8.30C (~MRQ)
/~NMI: J1.20C (~NMI), J2.20C (~NMI), J3.20C (~NMI), J4.20C (~NMI), J5.20C (~NMI), J6.20C (~NMI), J7.20C (~NMI), J8.20C (~NMI)
/~PWRCL: J1.26C (~PWRCL), J2.26C (~PWRCL), J3.26C (~PWRCL), J4.26C (~PWRCL), J5.26C (~PWRCL), J6.26C (~PWRCL), J7.26C (~PWRCL), J8.26C (~PWRCL), J13.1
/~RD: J1.24C (~RD), J2.24C (~RD), J3.24C (~RD), J4.24C (~RD), J5.24C (~RD), J6.24C (~RD), J7.24C (~RD), J8.24C (~RD)
/~RESET: J1.31C (~RESET), J2.31C (~RESET), J3.31C (~RESET), J4.31C (~RESET), J5.31C (~RESET), J6.31C (~RESET), J7.31C (~RESET), J8.31C (~RESET)
/~RFSH: J1.28A (~RFSH), J2.28A (~RFSH), J3.28A (~RFSH), J4.28A (~RFSH), J5.28A (~RFSH), J6.28A (~RFSH), J7.28A (~RFSH), J8.28A (~RFSH)
/~WAIT: J1.10A (~Wait), J2.10A (~Wait), J3.10A (~Wait), J4.10A (~Wait), J5.10A (~Wait), J6.10A (~Wait), J7.10A (~Wait), J8.10A (~Wait)
/~WR: J1.22C (~WR), J2.22C (~WR), J3.22C (~WR), J4.22C (~WR), J5.22C (~WR), J6.22C (~WR), J7.22C (~WR), J8.22C (~WR)
/~WrEn: J1.26A (~WrEn), J2.26A (~WrEn), J3.26A (~WrEn), J4.26A (~WrEn), J5.26A (~WrEn), J6.26A (~WrEn), J7.26A (~WrEn), J8.26A (~WrEn)
GND: J1.32A (GND), J1.32C (GND), J2.32A (GND), J2.32C (GND), J3.32A (GND), J3.32C (GND), J4.32A (GND), J4.32C (GND), J5.32A (GND), J5.32C (GND), J6.32A (GND), J6.32C (GND), J7.32A (GND), J7.32C (GND), J8.32A (GND), J8.32C (GND), J14.1

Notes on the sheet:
4,8mm Flackstecker

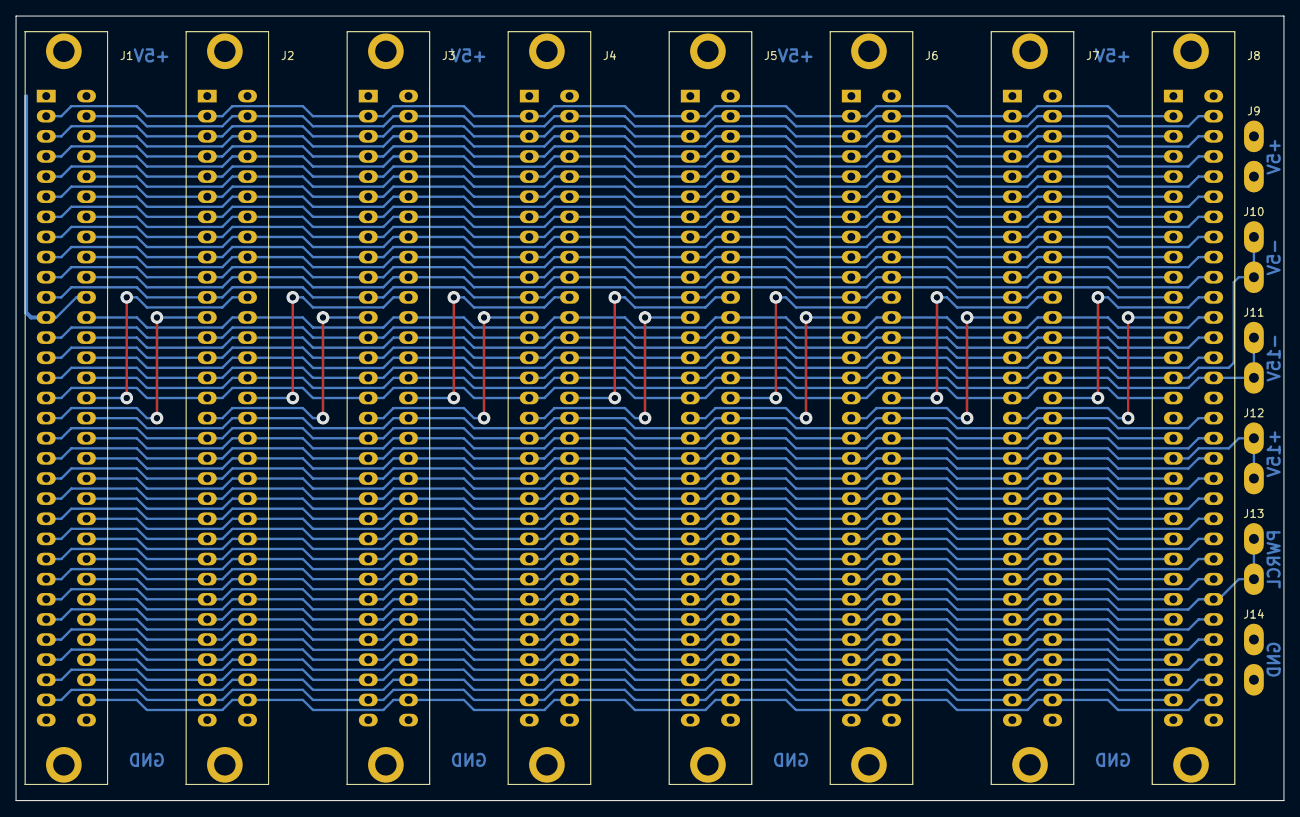
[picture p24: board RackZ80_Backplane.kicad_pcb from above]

Board: 2 copper layers, 160.0 x 99.0 mm, 14 parts (0 on the bottom side), 72 nets.

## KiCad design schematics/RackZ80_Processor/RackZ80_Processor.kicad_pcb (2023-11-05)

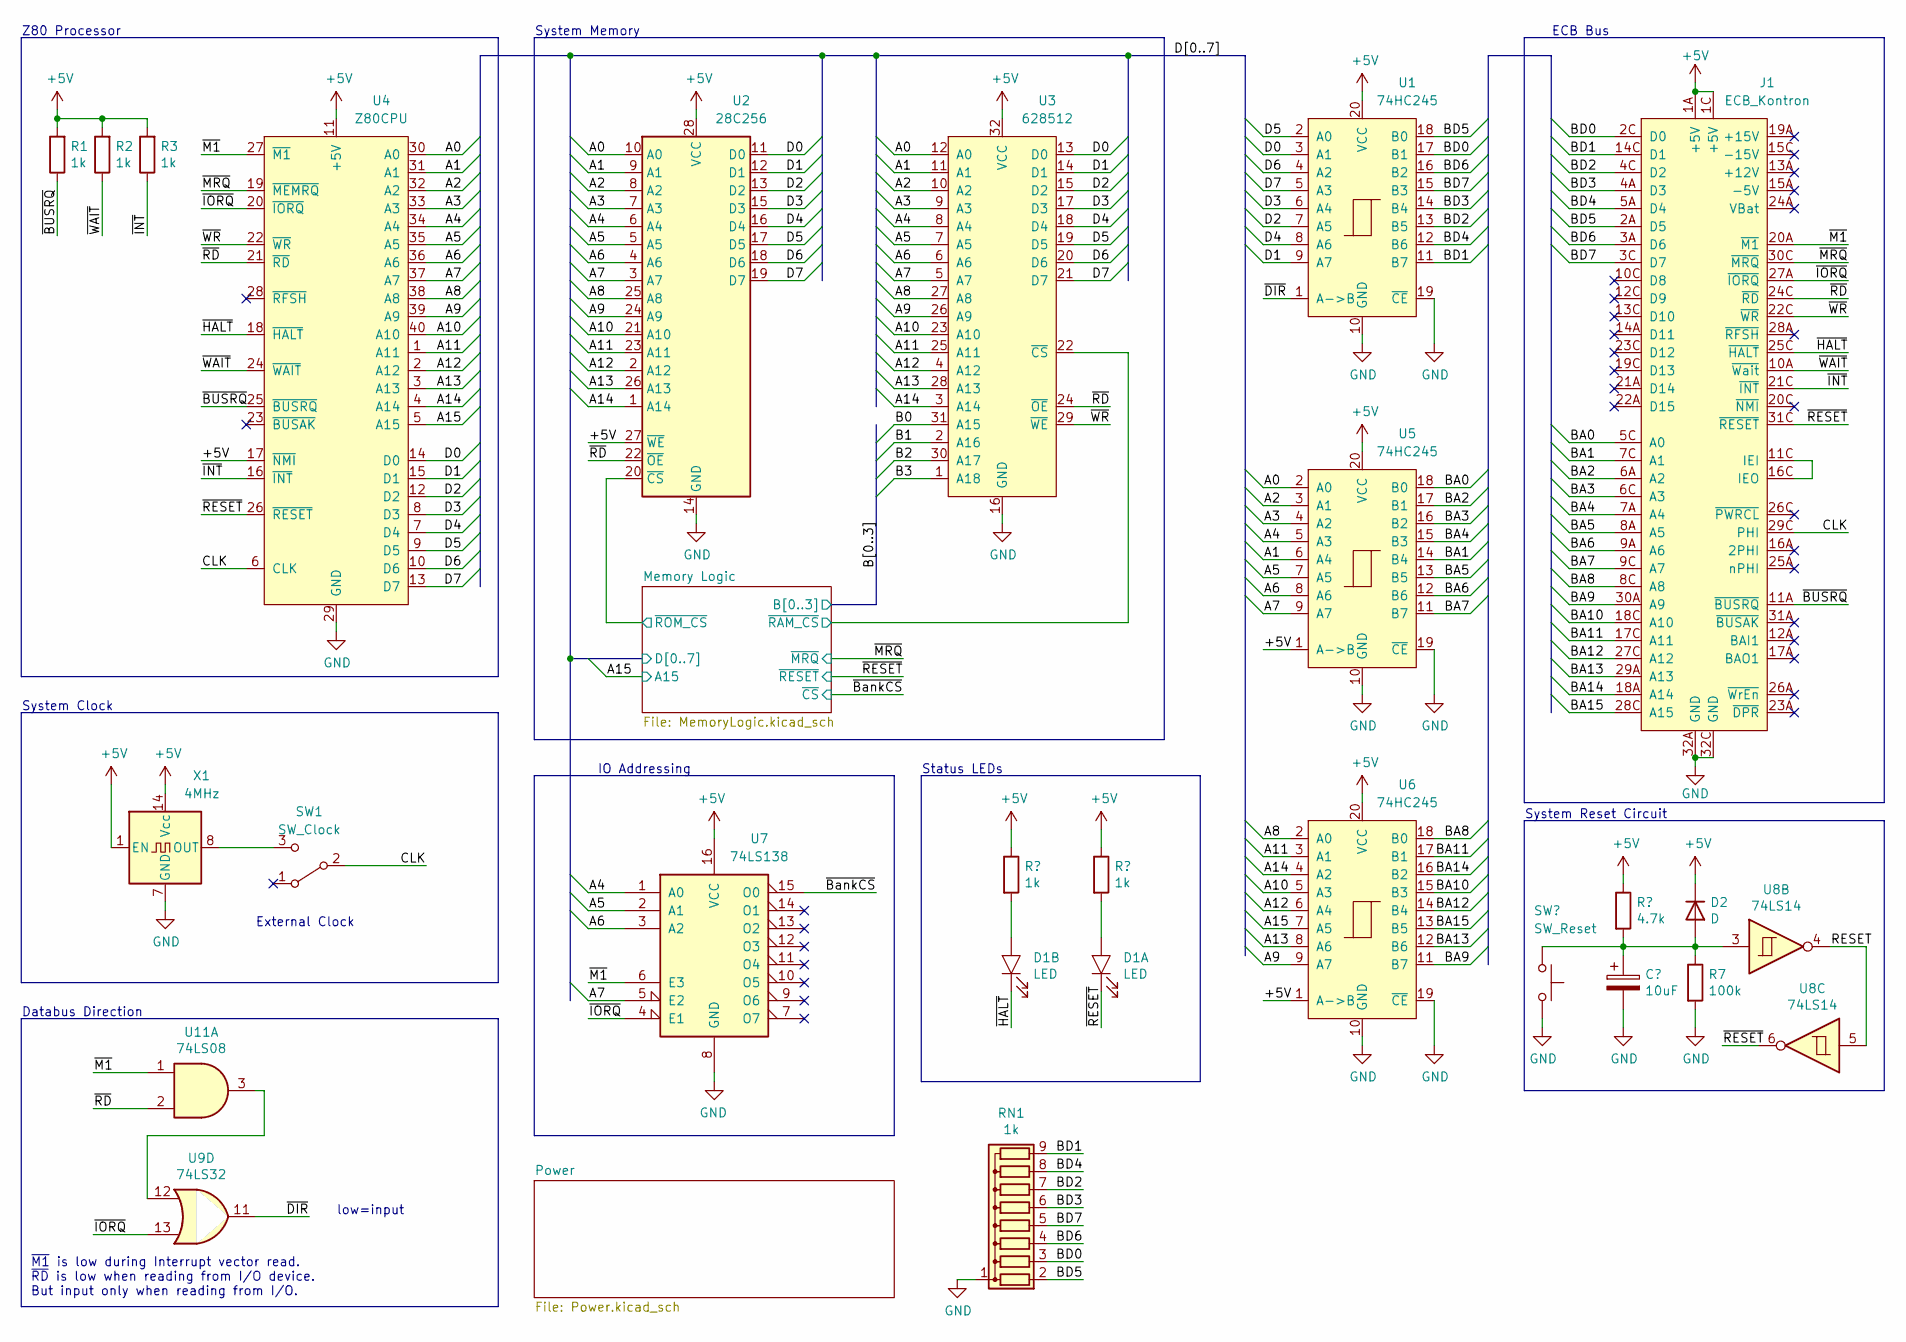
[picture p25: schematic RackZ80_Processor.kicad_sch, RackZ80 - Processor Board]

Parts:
C1: 10uF; CP_Radial_D5.0mm_P2.50mm
D1: LED; LED_Array_2
D2: D; D_DO-35_SOD27_P10.16mm_Horizontal
J1: ECB_Kontron; Eurocard_DIN41612_C64_Male
R1, R2, R3, R4, R5: 1k; R_Axial_DIN0207_L6.3mm_D2.5mm_P10.16mm_Horizontal
R6: 4.7k; R_Axial_DIN0207_L6.3mm_D2.5mm_P10.16mm_Horizontal
R7: 100k; R_Axial_DIN0207_L6.3mm_D2.5mm_P10.16mm_Horizontal
RN1: 1k; R_Array_SIP9
SW1: SW_Clock; SW_MS-500
SW2: SW_Reset; SW_MS-500
U1, U5, U6: 74HC245; DIP-20_Socket
U2: 28C256; DIP-28_Socket_Wide
U3: 628512; DIP-32_Socket_Wide
U4: Z80CPU; DIP-40_Socket_Wide
U7: 74LS138; DIP-16_Socket
U8: 74LS14; DIP-14_Socket
U9: 74LS32
U11: 74LS08; DIP-14_Socket
X1: 4MHz; DIP-14_Oscillator_Socket

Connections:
+5V: D2.1 (K), J1.1A (+5V), J1.1C (+5V), R1.2, R2.2, R3.2, R4.1, R5.1, R6.1, U1.20 (VCC), U2.27 (~WE), U2.28 (VCC), U3.32 (VCC), U4.11 (+5V), U4.17 (~NMI), U5.1 (A->B), U5.20 (VCC), U6.1 (A->B), U6.20 (VCC), U7.16 (VCC), X1.1 (EN), X1.14 (Vcc); also elsewhere on the board
/A0: U2.10 (A0), U3.12 (A0), U4.30 (A0), U5.2 (A0)
/A1: U2.9 (A1), U3.11 (A1), U4.31 (A1), U5.6 (A4)
/A2: U2.8 (A2), U3.10 (A2), U4.32 (A2), U5.3 (A1)
/A3: U2.7 (A3), U3.9 (A3), U4.33 (A3), U5.4 (A2)
/A4: U2.6 (A4), U3.8 (A4), U4.34 (A4), U5.5 (A3), U7.1 (A0)
/A5: U2.5 (A5), U3.7 (A5), U4.35 (A5), U5.7 (A5), U7.2 (A1)
/A6: U2.4 (A6), U3.6 (A6), U4.36 (A6), U5.8 (A6), U7.3 (A2)
/A7: U2.3 (A7), U3.5 (A7), U4.37 (A7), U5.9 (A7), U7.5 (E2)
/A8: U2.25 (A8), U3.27 (A8), U4.38 (A8), U6.2 (A0)
/A9: U2.24 (A9), U3.26 (A9), U4.39 (A9), U6.9 (A7)
/A10: U2.21 (A10), U3.23 (A10), U4.40 (A10), U6.5 (A3)
/A11: U2.23 (A11), U3.25 (A11), U4.1 (A11), U6.3 (A1)
/A12: U2.2 (A12), U3.4 (A12), U4.2 (A12), U6.6 (A4)
/A13: U2.26 (A13), U3.28 (A13), U4.3 (A13), U6.8 (A6)
/A14: U2.1 (A14), U3.3 (A14), U4.4 (A14), U6.4 (A2)
/A15: U4.5 (A15), U6.7 (A5); also elsewhere on the board
/B0: U3.31 (A15); also elsewhere on the board
/B1: U3.2 (A16); also elsewhere on the board
/B2: U3.30 (A17); also elsewhere on the board
/B3: U3.1 (A18); also elsewhere on the board
/BA0: J1.5C (A0), U5.18 (B0)
/BA1: J1.7C (A1), U5.14 (B4)
/BA2: J1.6A (A2), U5.17 (B1)
/BA3: J1.6C (A3), U5.16 (B2)
/BA4: J1.7A (A4), U5.15 (B3)
/BA5: J1.8A (A5), U5.13 (B5)
/BA6: J1.9A (A6), U5.12 (B6)
/BA7: J1.9C (A7), U5.11 (B7)
/BA8: J1.8C (A8), U6.18 (B0)
/BA9: J1.30A (A9), U6.11 (B7)
/BA10: J1.18C (A10), U6.15 (B3)
/BA11: J1.17C (A11), U6.17 (B1)
/BA12: J1.27C (A12), U6.14 (B4)
/BA13: J1.29A (A13), U6.12 (B6)
/BA14: J1.18A (A14), U6.16 (B2)
/BA15: J1.28C (A15), U6.13 (B5)
/BD0: J1.2C (D0), RN1.3 (R2), U1.17 (B1)
/BD1: J1.14C (D1), RN1.9 (R8), U1.11 (B7)
/BD2: J1.4C (D2), RN1.7 (R6), U1.13 (B5)
/BD3: J1.4A (D3), RN1.6 (R5), U1.14 (B4)
/BD4: J1.5A (D4), RN1.8 (R7), U1.12 (B6)
/BD5: J1.2A (D5), RN1.2 (R1), U1.18 (B0)
/BD6: J1.3A (D6), RN1.4 (R3), U1.16 (B2)
/BD7: J1.3C (D7), RN1.5 (R4), U1.15 (B3)
/CLK: J1.29C (PHI), SW1.2 (B), U4.6 (CLK)
/D0: U1.3 (A1), U2.11 (D0), U3.13 (D0), U4.14 (D0); also elsewhere on the board
/D1: U1.9 (A7), U2.12 (D1), U3.14 (D1), U4.15 (D1); also elsewhere on the board
/D2: U1.7 (A5), U2.13 (D2), U3.15 (D2), U4.12 (D2); also elsewhere on the board
/D3: U1.6 (A4), U2.15 (D3), U3.17 (D3), U4.8 (D3); also elsewhere on the board
/D4: U1.8 (A6), U2.16 (D4), U3.18 (D4), U4.7 (D4); also elsewhere on the board
/D5: U1.2 (A0), U2.17 (D5), U3.19 (D5), U4.9 (D5)
/D6: U1.4 (A2), U2.18 (D6), U3.20 (D6), U4.10 (D6)
/D7: U1.5 (A3), U2.19 (D7), U3.21 (D7), U4.13 (D7)
/Memory Logic/~RAM_CS: U3.22 (~CS); also elsewhere on the board
/Memory Logic/~ROM_CS: U2.20 (~CS); also elsewhere on the board
/RESET: U8.4, U8.5
/~BUSRQ: J1.11A (~BUSRQ), R1.1, U4.25 (~BUSRQ)
/~BankCS: U7.15 (O0); also elsewhere on the board
/~DIR: U1.1 (A->B), U9.11
/~HALT: D1.3 (K), J1.25C (~HALT), U4.18 (~HALT)
/~INT: J1.21C (~INT), R3.1, U4.16 (~INT)
/~IORQ: J1.27A (~IORQ), U4.20 (~IORQ), U7.4 (E1), U9.13
/~M1: J1.20A (~M1), U4.27 (~M1), U7.6 (E3), U11.1
/~MRQ: J1.30C (~MRQ), U4.19 (~MEMRQ); also elsewhere on the board
/~RD: J1.24C (~RD), U2.22 (~OE), U3.24 (~OE), U4.21 (~RD), U11.2
/~RESET: D1.1 (K), J1.31C (~RESET), U4.26 (~RESET), U8.6; also elsewhere on the board
/~WAIT: J1.10A (~Wait), R2.1, U4.24 (~WAIT)
/~WR: J1.22C (~WR), U3.29 (~WE), U4.22 (~WR)
GND: C1.2, J1.32A (GND), J1.32C (GND), R7.2, RN1.1 (common), SW2.1, U1.10 (GND), U1.19 (~CE), U2.14 (GND), U3.16 (GND), U4.29 (GND), U5.10 (GND), U5.19 (~CE), U6.10 (GND), U6.19 (~CE), U7.8 (GND), X1.7 (GND); also elsewhere on the board
unnamed: C1.1, D2.2 (A), R6.2, R7.1, SW2.2, U8.3
unnamed: D1.2 (A), R5.2
unnamed: D1.4 (A), R4.2
unnamed: J1.11C (IEI), J1.16C (IEO)
unnamed: SW1.3 (C), X1.8 (OUT)
unnamed: U9.12, U11.3

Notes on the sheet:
System Reset Circuit
Databus Direction
low=input
IO Addressing
Status LEDs
Z80 Processor
~{M1} is low during Interrupt vector read. ~{RD} is low when reading from I/O device. But input only when reading from I/O.
External Clock
System Memory
System Clock
ECB Bus

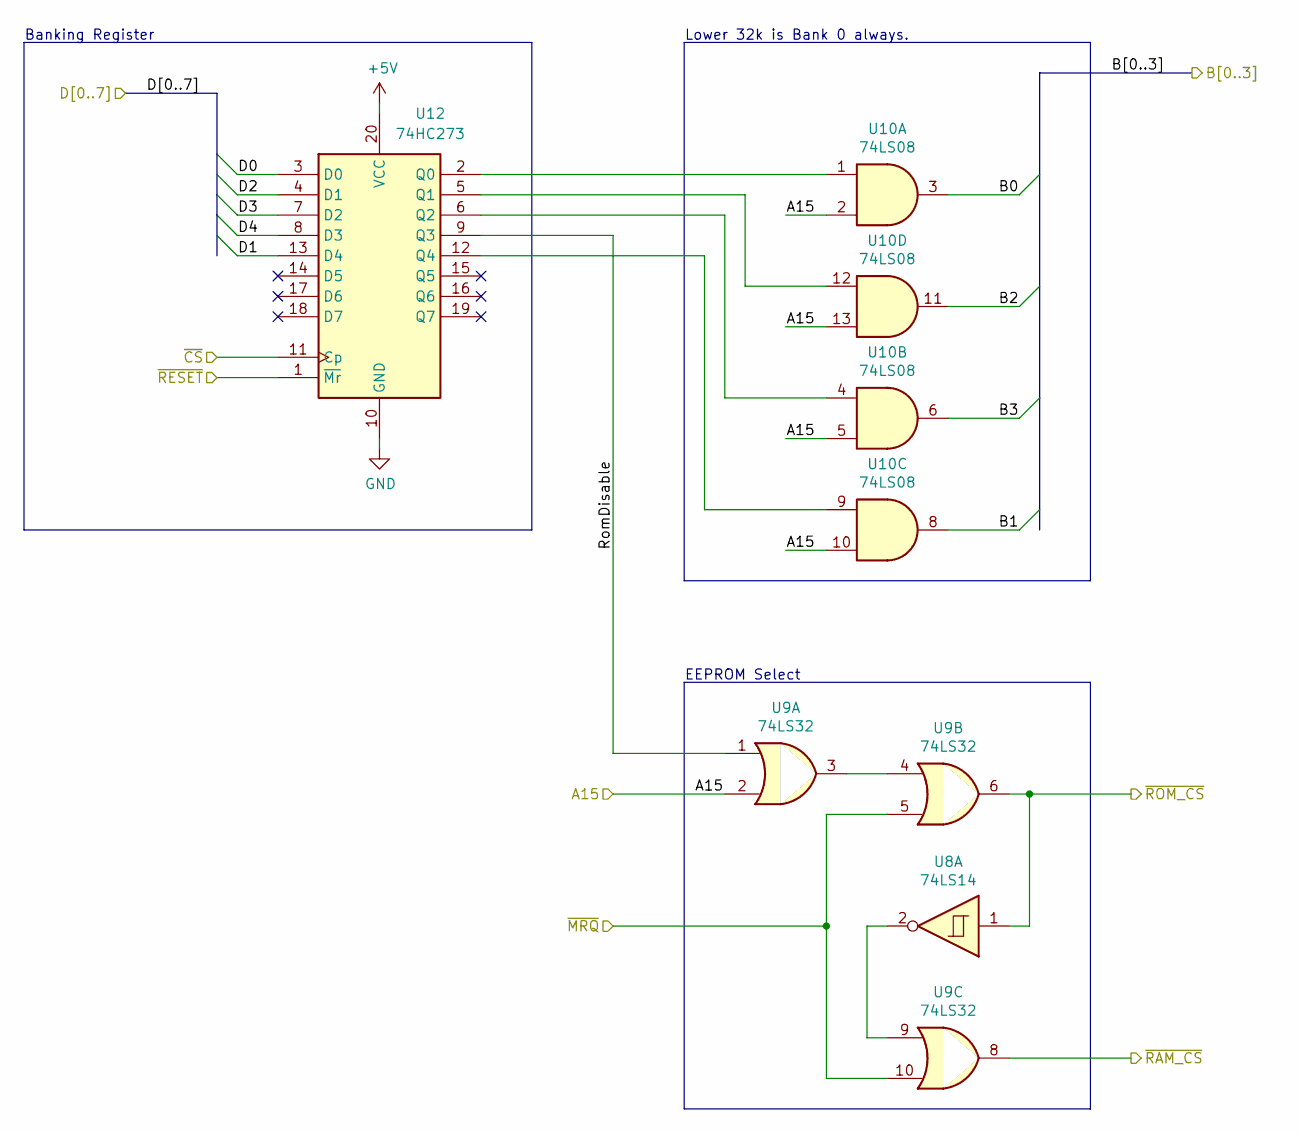
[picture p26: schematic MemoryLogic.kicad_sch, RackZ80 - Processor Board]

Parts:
U8: 74LS14; DIP-14_Socket
U9: 74LS32; DIP-14_Socket
U10: 74LS08; DIP-14_Socket
U12: 74HC273; DIP-20_Socket

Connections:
+5V: U12.20 (VCC); also elsewhere on the board
/A15: U9.2, U10.2, U10.5, U10.10, U10.13; also elsewhere on the board
/B0: U10.3; also elsewhere on the board
/B1: U10.8; also elsewhere on the board
/B2: U10.11; also elsewhere on the board
/B3: U10.6; also elsewhere on the board
/D0: U12.3 (D0); also elsewhere on the board
/D1: U12.13 (D4); also elsewhere on the board
/D2: U12.4 (D1); also elsewhere on the board
/D3: U12.7 (D2); also elsewhere on the board
/D4: U12.8 (D3); also elsewhere on the board
/Memory Logic/RomDisable: U9.1, U12.9 (Q3)
/Memory Logic/~RAM_CS: U9.8; also elsewhere on the board
/Memory Logic/~ROM_CS: U8.1, U9.6; also elsewhere on the board
/~BankCS: U12.11 (Cp); also elsewhere on the board
/~MRQ: U9.5, U9.10; also elsewhere on the board
/~RESET: U12.1 (~Mr); also elsewhere on the board
GND: U12.10 (GND); also elsewhere on the board
unnamed: U8.2, U9.9
unnamed: U9.3, U9.4
unnamed: U10.1, U12.2 (Q0)
unnamed: U10.4, U12.6 (Q2)
unnamed: U10.9, U12.12 (Q4)
unnamed: U10.12, U12.5 (Q1)

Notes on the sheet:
Banking Register
Lower 32k is Bank 0 always.
EEPROM Select

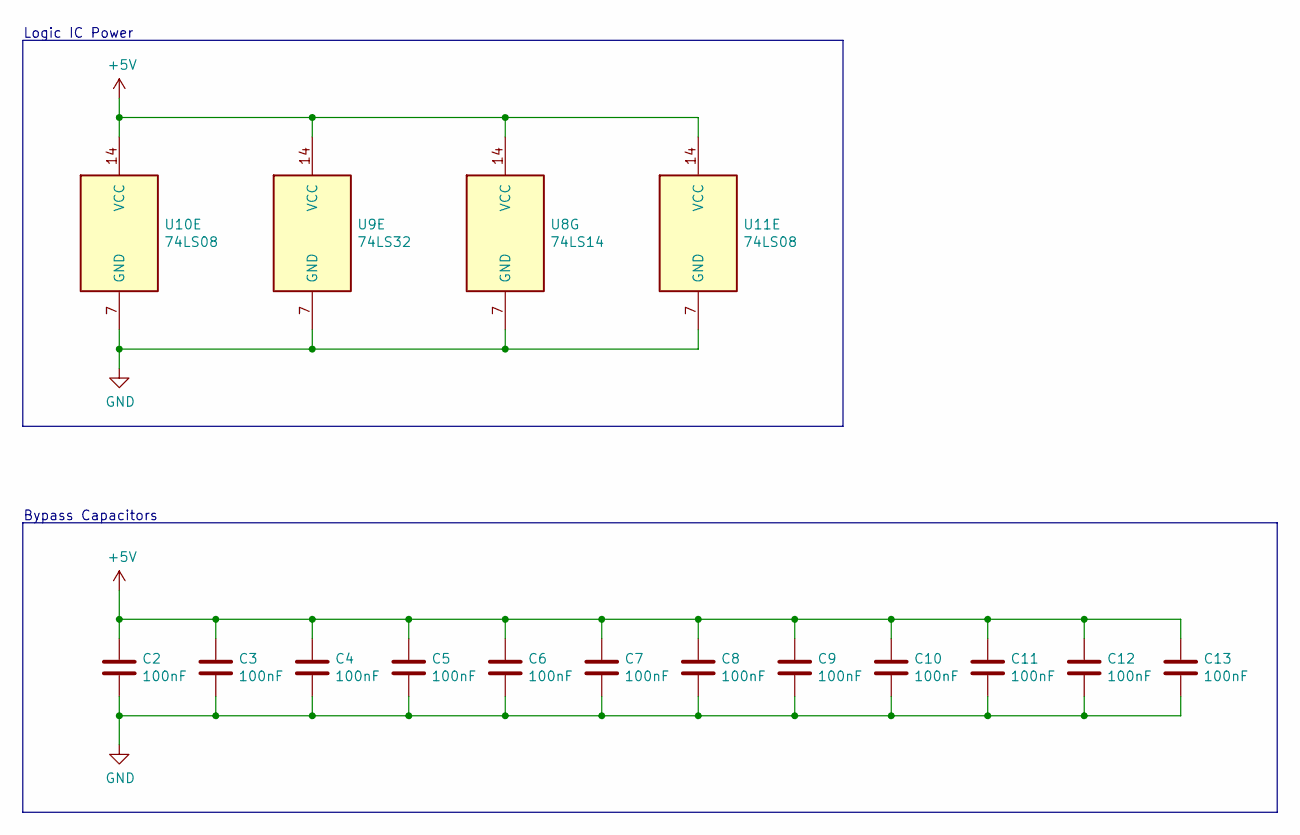
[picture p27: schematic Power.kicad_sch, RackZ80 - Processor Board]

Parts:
C2, C3, C4, C5, C6, C7, C8, C9, C10, C11, C12, C13: 100nF; C_Disc_D4.3mm_W1.9mm_P5.00mm
U8: 74LS14; DIP-14_Socket
U9: 74LS32; DIP-14_Socket
U10, U11: 74LS08; DIP-14_Socket

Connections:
+5V: C2.1, C3.1, C4.1, C5.1, C6.1, C7.1, C8.1, C9.1, C10.1, C11.1, C12.1, C13.1, U8.14 (VCC), U9.14 (VCC), U10.14 (VCC), U11.14 (VCC); also elsewhere on the board
GND: C2.2, C3.2, C4.2, C5.2, C6.2, C7.2, C8.2, C9.2, C10.2, C11.2, C12.2, C13.2, U8.7 (GND), U9.7 (GND), U10.7 (GND), U11.7 (GND); also elsewhere on the board

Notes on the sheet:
Bypass Capacitors
Logic IC Power

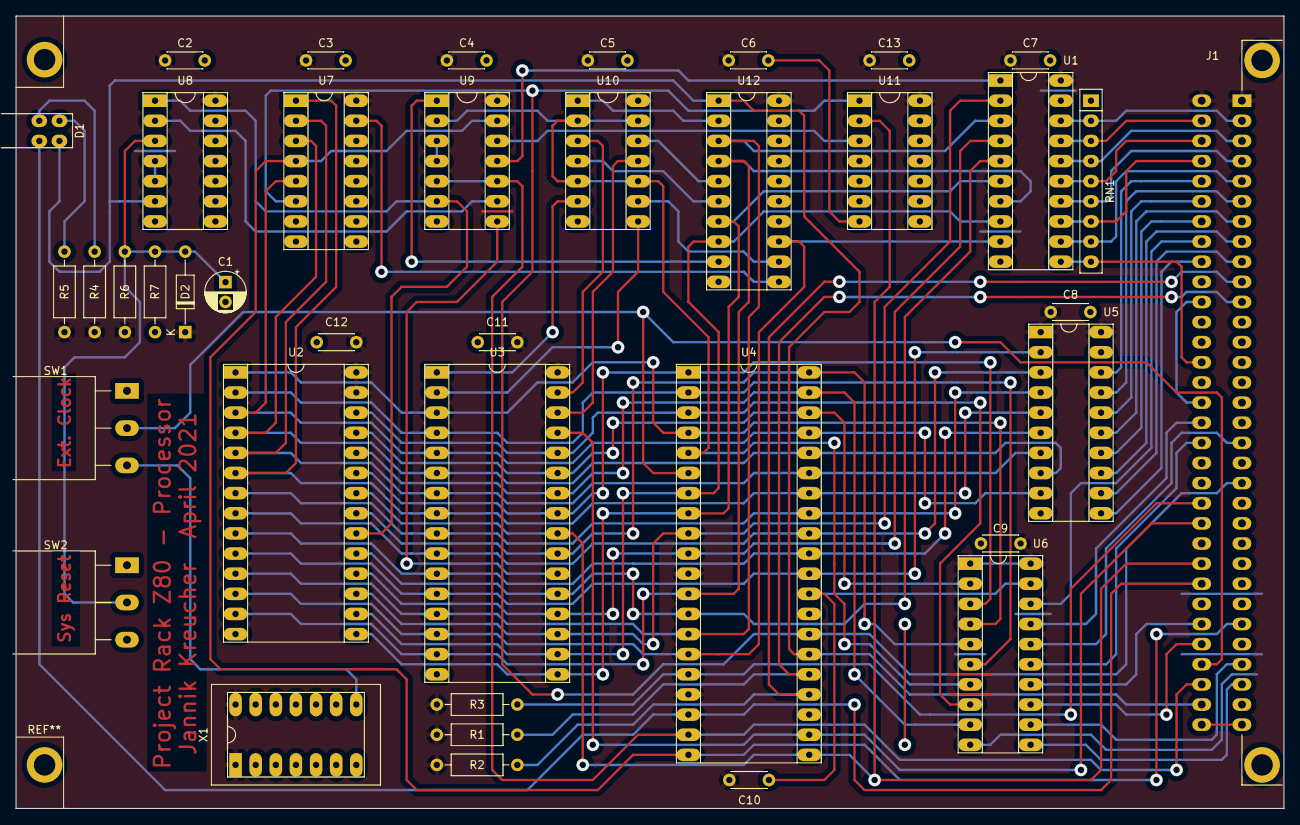
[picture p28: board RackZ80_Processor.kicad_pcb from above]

Board: 2 copper layers, 160.0 x 100.0 mm, 39 parts (0 on the bottom side), 83 nets.

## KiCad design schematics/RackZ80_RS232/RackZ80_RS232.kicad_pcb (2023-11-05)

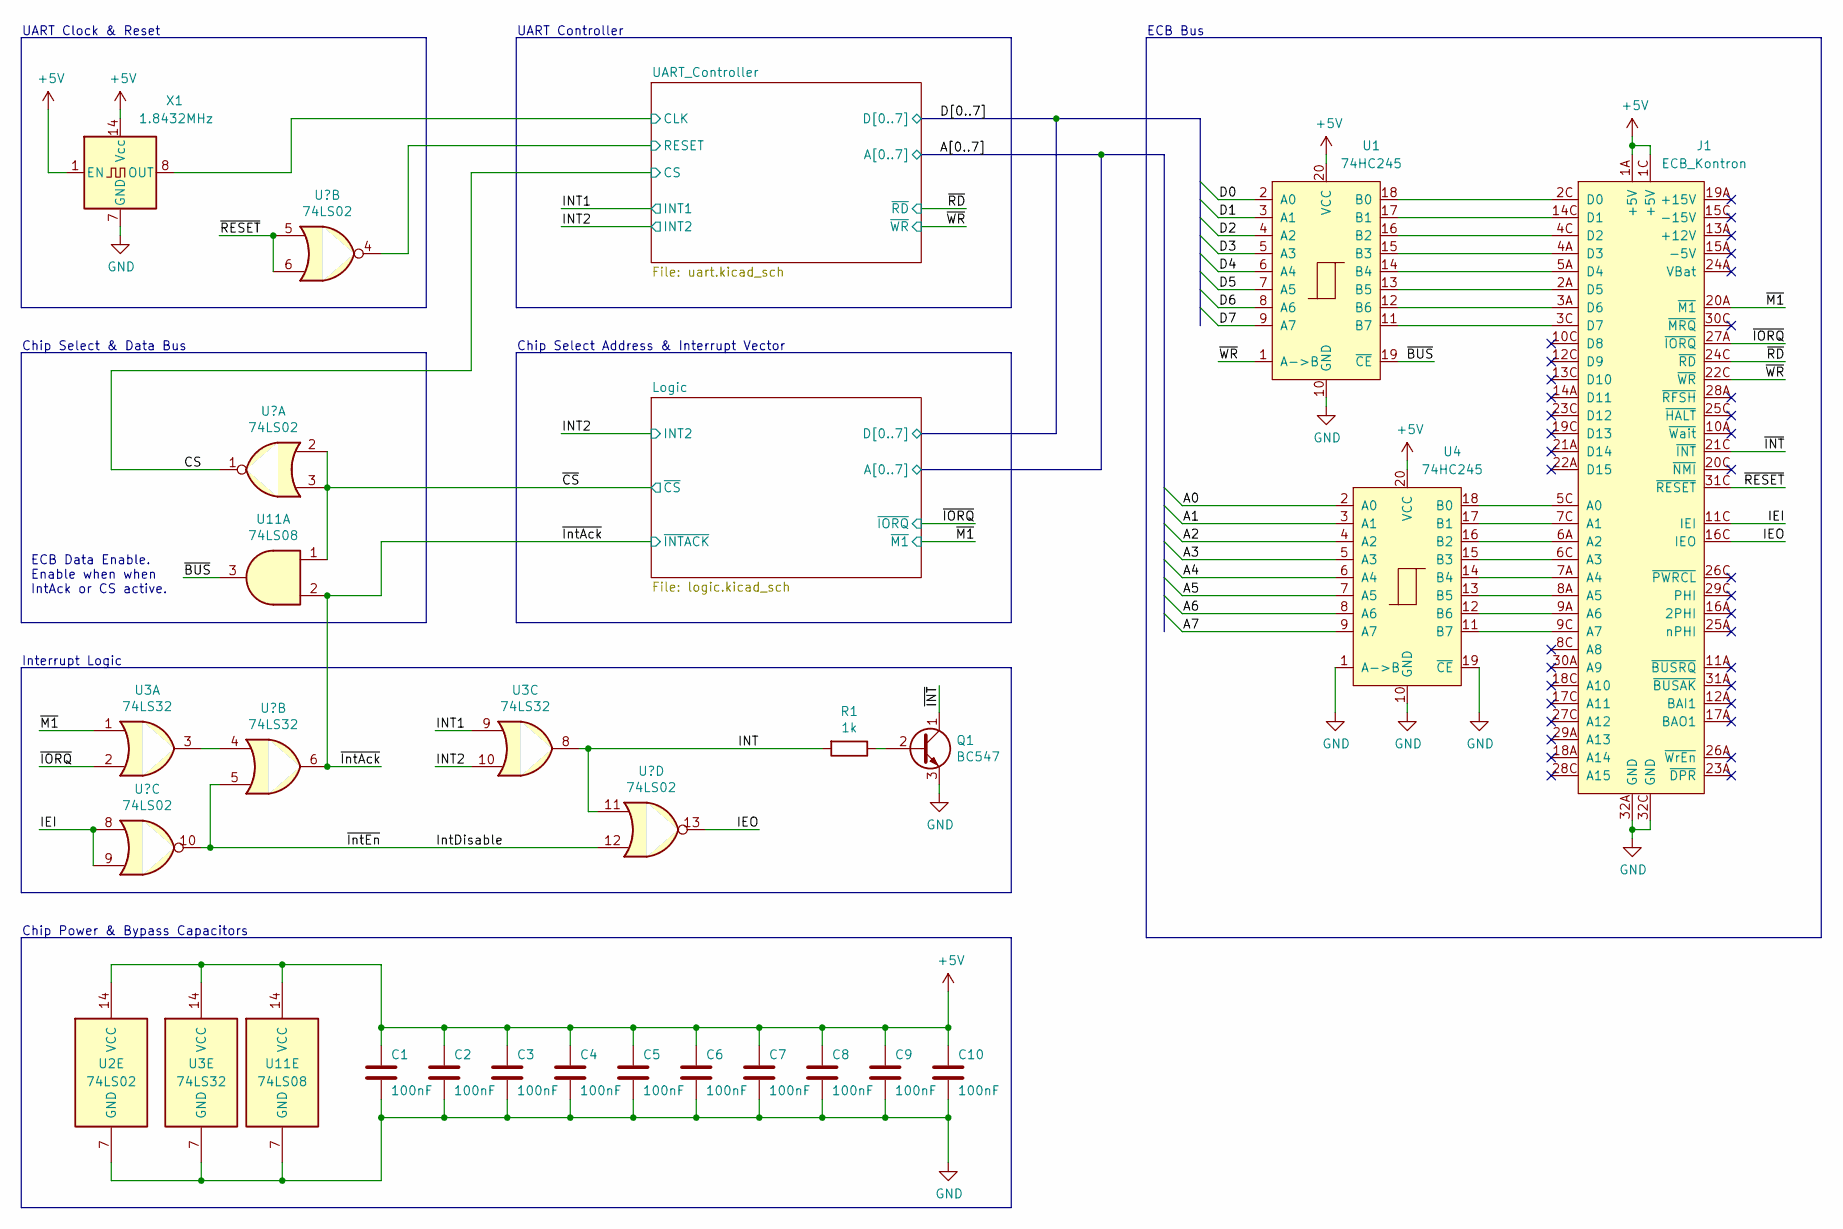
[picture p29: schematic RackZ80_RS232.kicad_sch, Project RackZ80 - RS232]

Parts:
C1, C2, C3, C4, C5, C6, C7, C8, C9, C10: 100nF; C_Disc_D4.3mm_W1.9mm_P5.00mm
J1: ECB_Kontron; Eurocard_DIN41612_C64_Male
Q1: BC547; TO-92S_Wide
R1: 1k; R_Axial_DIN0207_L6.3mm_D2.5mm_P10.16mm_Horizontal
U1, U4: 74HC245; DIP-20_Socket
U2: 74LS02; DIP-14_Socket
U3: 74LS32; DIP-14_Socket
U11: 74LS08; DIP-14_Socket
X1: 1.8432MHz; DIP-14_Oscillator_Socket

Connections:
+5V: C1.1, C2.1, C3.1, C4.1, C5.1, C6.1, C7.1, C8.1, C9.1, C10.1, J1.1A (+5V), J1.1C (+5V), U1.20 (VCC), U2.14 (VCC), U3.14 (VCC), U4.20 (VCC), U11.14 (VCC), X1.1 (EN), X1.14 (Vcc); also elsewhere on the board
/A0: U4.2 (A0); also elsewhere on the board
/A1: U4.3 (A1); also elsewhere on the board
/A2: U4.4 (A2); also elsewhere on the board
/A3: U4.5 (A3); also elsewhere on the board
/A4: U4.6 (A4); also elsewhere on the board
/A5: U4.7 (A5); also elsewhere on the board
/A6: U4.8 (A6); also elsewhere on the board
/A7: U4.9 (A7); also elsewhere on the board
/CS: U2.1; also elsewhere on the board
/D0: U1.2 (A0); also elsewhere on the board
/D1: U1.3 (A1); also elsewhere on the board
/D2: U1.4 (A2); also elsewhere on the board
/D3: U1.5 (A3); also elsewhere on the board
/D4: U1.6 (A4); also elsewhere on the board
/D5: U1.7 (A5); also elsewhere on the board
/D6: U1.8 (A6); also elsewhere on the board
/D7: U1.9 (A7); also elsewhere on the board
/IEI: J1.11C (IEI), U2.8, U2.9
/IEO: J1.16C (IEO), U2.13
/INT: R1.2, U2.11, U3.8
/INT1: U3.9; also elsewhere on the board
/INT2: U3.10; also elsewhere on the board
/IntDisable: U2.10, U2.12, U3.5
/UART_Controller/CLK: X1.8 (OUT); also elsewhere on the board
/UART_Controller/RESET: U2.4; also elsewhere on the board
/~BUS: U1.19 (~CE), U11.3
/~CS: U2.2, U2.3, U11.1; also elsewhere on the board
/~INT: J1.21C (~INT), Q1.1 (C)
/~IORQ: J1.27A (~IORQ), U3.2; also elsewhere on the board
/~IntAck: U3.6, U11.2; also elsewhere on the board
/~M1: J1.20A (~M1), U3.1; also elsewhere on the board
/~RD: J1.24C (~RD); also elsewhere on the board
/~RESET: J1.31C (~RESET), U2.5, U2.6
/~WR: J1.22C (~WR), U1.1 (A->B); also elsewhere on the board
GND: C1.2, C2.2, C3.2, C4.2, C5.2, C6.2, C7.2, C8.2, C9.2, C10.2, J1.32A (GND), J1.32C (GND), Q1.3 (E), U1.10 (GND), U2.7 (GND), U3.7 (GND), U4.1 (A->B), U4.10 (GND), U4.19 (~CE), U11.7 (GND), X1.7 (GND); also elsewhere on the board
unnamed: J1.2A (D5), U1.13 (B5)
unnamed: J1.2C (D0), U1.18 (B0)
unnamed: J1.3A (D6), U1.12 (B6)
unnamed: J1.3C (D7), U1.11 (B7)
unnamed: J1.4A (D3), U1.15 (B3)
unnamed: J1.4C (D2), U1.16 (B2)
unnamed: J1.5A (D4), U1.14 (B4)
unnamed: J1.5C (A0), U4.18 (B0)
unnamed: J1.6A (A2), U4.16 (B2)
unnamed: J1.6C (A3), U4.15 (B3)
unnamed: J1.7A (A4), U4.14 (B4)
unnamed: J1.7C (A1), U4.17 (B1)
unnamed: J1.8A (A5), U4.13 (B5)
unnamed: J1.9A (A6), U4.12 (B6)
unnamed: J1.9C (A7), U4.11 (B7)
unnamed: J1.14C (D1), U1.17 (B1)
unnamed: Q1.2 (B), R1.1
unnamed: U3.3, U3.4

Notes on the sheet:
UART Controller
Chip Power & Bypass Capacitors
ECB Bus
Interrupt Logic
Chip Select & Data Bus
Chip Select Address & Interrupt Vector
UART Clock & Reset
ECB Data Enable. Enable when when IntAck or CS active.

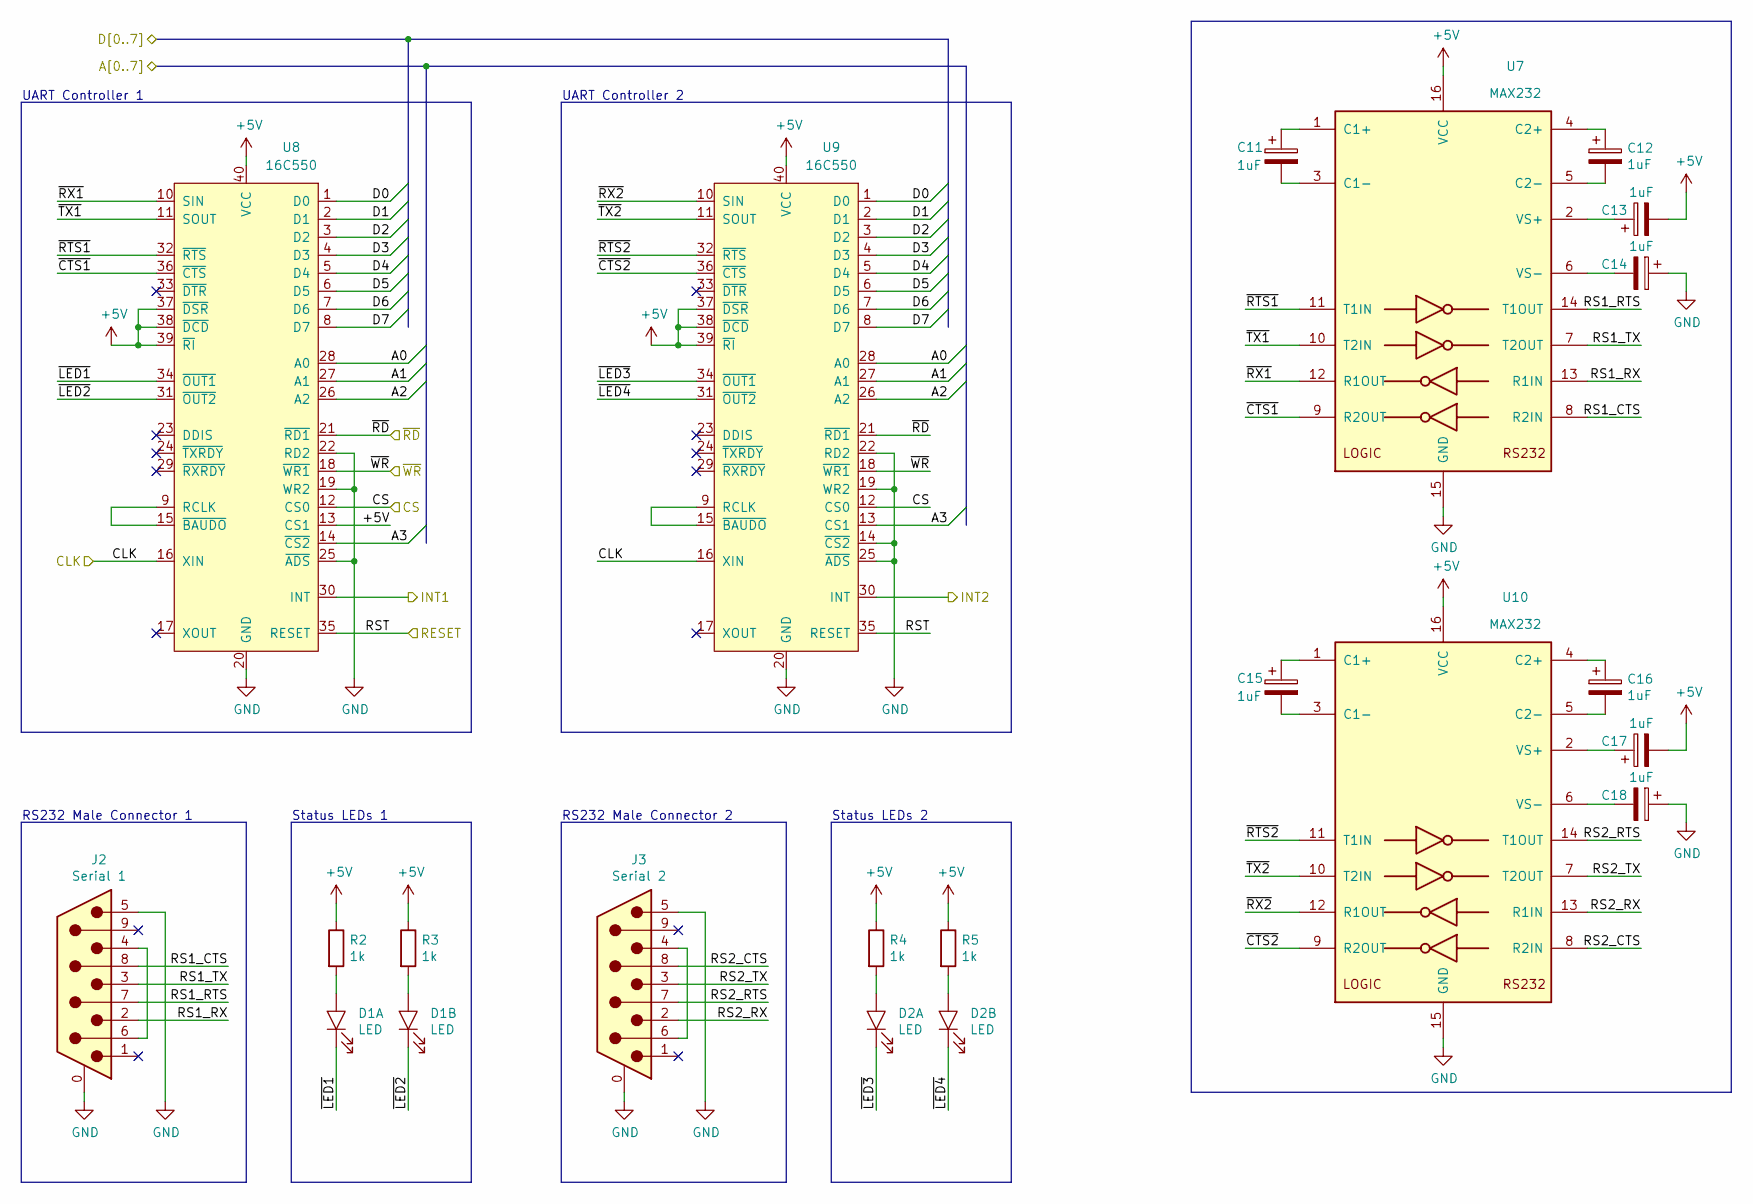
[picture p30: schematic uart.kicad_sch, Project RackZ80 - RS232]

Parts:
C11, C12, C13, C14, C15, C16, C17, C18: 1uF; CP_Radial_D5.0mm_P2.00mm
D1, D2: LED; LED_Array_2
J2: Serial 1; DSUB-9_Male_Horizontal_P2.77x2.84mm_EdgePinOffset9.90mm_Hou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
J3: Serial 2; DSUB-9_Male_Horizontal_P2.77x2.84mm_EdgePinOffset9.90mm_Hou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
R2, R3, R4, R5: 1k; R_Axial_DIN0207_L6.3mm_D2.5mm_P10.16mm_Horizontal
U7, U10: MAX232; DIP-16_Socket
U8, U9: 16C550; DIP-40_Socket_Wide

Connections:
+5V: C13.2, C17.2, R2.1, R3.1, R4.1, R5.1, U7.16 (VCC), U8.13 (CS1), U8.37 (~DSR), U8.38 (~DCD), U8.39 (~RI), U8.40 (VCC), U9.37 (~DSR), U9.38 (~DCD), U9.39 (~RI), U9.40 (VCC), U10.16 (VCC); also elsewhere on the board
/A0: U8.28 (A0), U9.28 (A0); also elsewhere on the board
/A1: U8.27 (A1), U9.27 (A1); also elsewhere on the board
/A2: U8.26 (A2), U9.26 (A2); also elsewhere on the board
/A3: U8.14 (~CS2), U9.13 (CS1); also elsewhere on the board
/CS: U8.12 (CS0), U9.12 (CS0); also elsewhere on the board
/D0: U8.1 (D0), U9.1 (D0); also elsewhere on the board
/D1: U8.2 (D1), U9.2 (D1); also elsewhere on the board
/D2: U8.3 (D2), U9.3 (D2); also elsewhere on the board
/D3: U8.4 (D3), U9.4 (D3); also elsewhere on the board
/D4: U8.5 (D4), U9.5 (D4); also elsewhere on the board
/D5: U8.6 (D5), U9.6 (D5); also elsewhere on the board
/D6: U8.7 (D6), U9.7 (D6); also elsewhere on the board
/D7: U8.8 (D7), U9.8 (D7); also elsewhere on the board
/INT1: U8.30 (INT); also elsewhere on the board
/INT2: U9.30 (INT); also elsewhere on the board
/UART_Controller/CLK: U8.16 (XIN), U9.16 (XIN); also elsewhere on the board
/UART_Controller/RESET: U8.35 (RESET), U9.35 (RESET); also elsewhere on the board
/UART_Controller/RS1_CTS: J2.8, U7.8 (R2IN)
/UART_Controller/RS1_RTS: J2.7, U7.14 (T1OUT)
/UART_Controller/RS1_RX: J2.2, U7.13 (R1IN)
/UART_Controller/RS1_TX: J2.3, U7.7 (T2OUT)
/UART_Controller/RS2_CTS: J3.8, U10.8 (R2IN)
/UART_Controller/RS2_RTS: J3.7, U10.14 (T1OUT)
/UART_Controller/RS2_RX: J3.2, U10.13 (R1IN)
/UART_Controller/RS2_TX: J3.3, U10.7 (T2OUT)
/UART_Controller/~CTS1: U7.9 (R2OUT), U8.36 (~CTS)
/UART_Controller/~CTS2: U9.36 (~CTS), U10.9 (R2OUT)
/UART_Controller/~LED1: D1.1 (K), U8.34 (~OUT1)
/UART_Controller/~LED2: D1.3 (K), U8.31 (~OUT2)
/UART_Controller/~LED3: D2.1 (K), U9.34 (~OUT1)
/UART_Controller/~LED4: D2.3 (K), U9.31 (~OUT2)
/UART_Controller/~RTS1: U7.11 (T1IN), U8.32 (~RTS)
/UART_Controller/~RTS2: U9.32 (~RTS), U10.11 (T1IN)
/UART_Controller/~RX1: U7.12 (R1OUT), U8.10 (SIN)
/UART_Controller/~RX2: U9.10 (SIN), U10.12 (R1OUT)
/UART_Controller/~TX1: U7.10 (T2IN), U8.11 (SOUT)
/UART_Controller/~TX2: U9.11 (SOUT), U10.10 (T2IN)
/~RD: U8.21 (~RD1), U9.21 (~RD1); also elsewhere on the board
/~WR: U8.18 (~WR1), U9.18 (~WR1); also elsewhere on the board
GND: C14.1, C18.1, J2.0 (PAD), J2.5, J3.0 (PAD), J3.5, U7.15 (GND), U8.19 (WR2), U8.20 (GND), U8.22 (RD2), U8.25 (~ADS), U9.14 (~CS2), U9.19 (WR2), U9.20 (GND), U9.22 (RD2), U9.25 (~ADS), U10.15 (GND); also elsewhere on the board
unnamed: C11.1, U7.1 (C1+)
unnamed: C11.2, U7.3 (C1-)
unnamed: C12.1, U7.4 (C2+)
unnamed: C12.2, U7.5 (C2-)
unnamed: C13.1, U7.2 (VS+)
unnamed: C14.2, U7.6 (VS-)
unnamed: C15.1, U10.1 (C1+)
unnamed: C15.2, U10.3 (C1-)
unnamed: C16.1, U10.4 (C2+)
unnamed: C16.2, U10.5 (C2-)
unnamed: C17.1, U10.2 (VS+)
unnamed: C18.2, U10.6 (VS-)
unnamed: D1.2 (A), R2.2
unnamed: D1.4 (A), R3.2
unnamed: D2.2 (A), R4.2
unnamed: D2.4 (A), R5.2
unnamed: J2.4, J2.6
unnamed: J3.4, J3.6
unnamed: U8.9 (RCLK), U8.15 (~BAUDO)
unnamed: U9.9 (RCLK), U9.15 (~BAUDO)

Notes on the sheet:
RS232 Male Connector 1
UART Controller 2
Status LEDs 1
RS232 Male Connector 2
Status LEDs 2
UART Controller 1

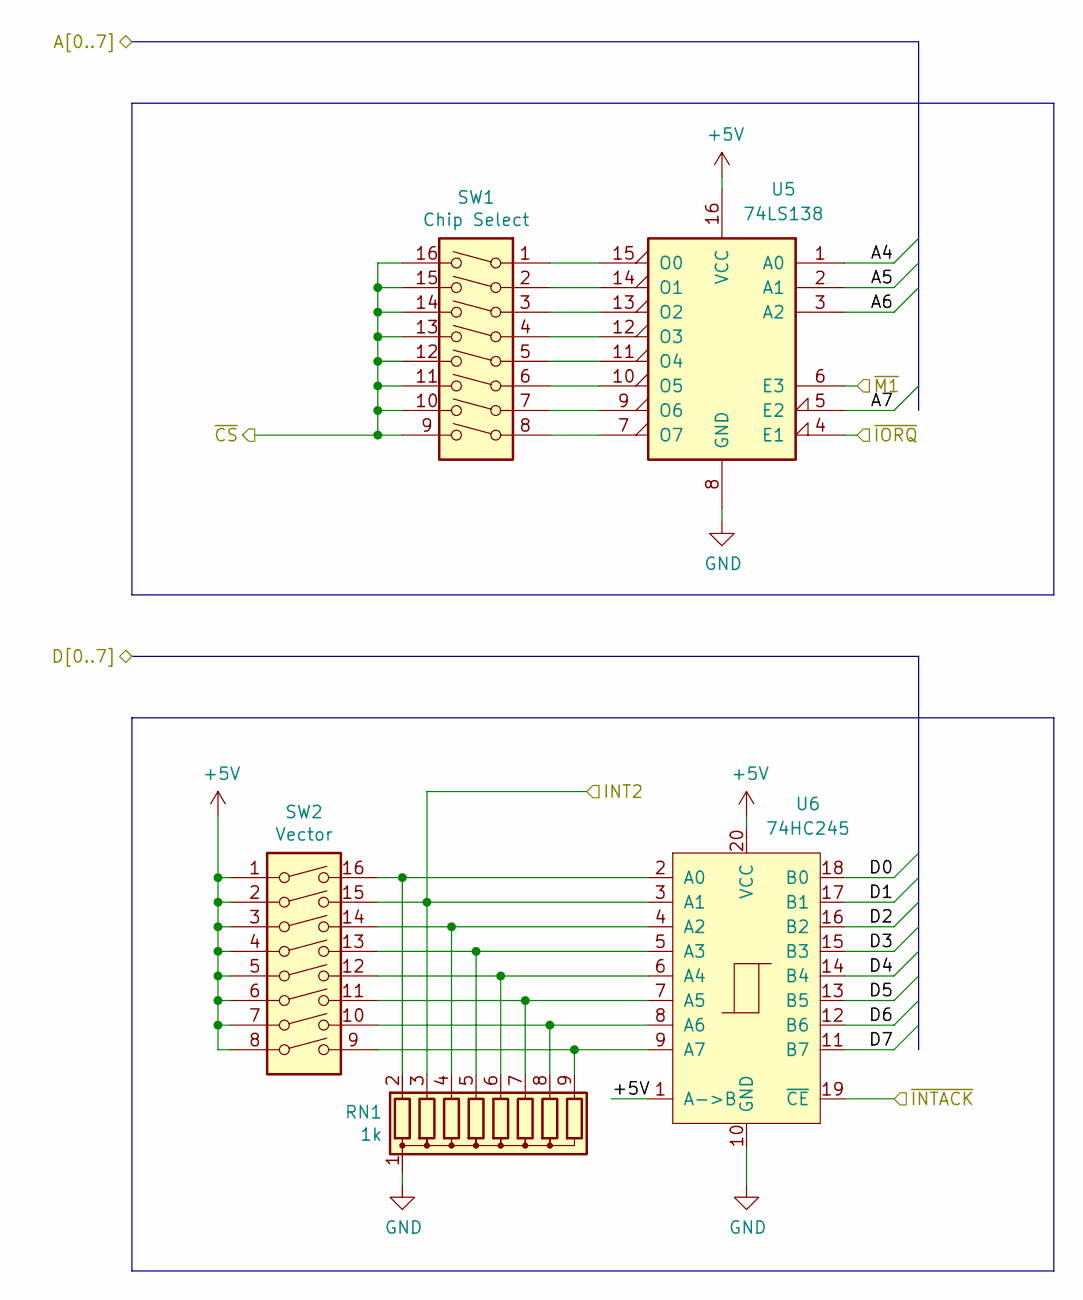
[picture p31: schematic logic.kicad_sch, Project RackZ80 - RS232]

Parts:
RN1: 1k; R_Array_SIP9
SW1: Chip Select; SW_DIP_SPSTx08_Slide_9.78x22.5mm_W7.62mm_P2.54mm
SW2: Vector; SW_DIP_SPSTx08_Slide_9.78x22.5mm_W7.62mm_P2.54mm
U5: 74LS138; DIP-16_Socket
U6: 74HC245; DIP-20_Socket

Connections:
+5V: SW2.1, SW2.2, SW2.3, SW2.4, SW2.5, SW2.6, SW2.7, SW2.8, U5.16 (VCC), U6.1 (A->B), U6.20 (VCC); also elsewhere on the board
/A4: U5.1 (A0); also elsewhere on the board
/A5: U5.2 (A1); also elsewhere on the board
/A6: U5.3 (A2); also elsewhere on the board
/A7: U5.5 (E2); also elsewhere on the board
/D0: U6.18 (B0); also elsewhere on the board
/D1: U6.17 (B1); also elsewhere on the board
/D2: U6.16 (B2); also elsewhere on the board
/D3: U6.15 (B3); also elsewhere on the board
/D4: U6.14 (B4); also elsewhere on the board
/D5: U6.13 (B5); also elsewhere on the board
/D6: U6.12 (B6); also elsewhere on the board
/D7: U6.11 (B7); also elsewhere on the board
/INT2: RN1.3 (R2), SW2.15, U6.3 (A1); also elsewhere on the board
/~CS: SW1.9, SW1.10, SW1.11, SW1.12, SW1.13, SW1.14, SW1.15, SW1.16; also elsewhere on the board
/~IORQ: U5.4 (E1); also elsewhere on the board
/~IntAck: U6.19 (~CE); also elsewhere on the board
/~M1: U5.6 (E3); also elsewhere on the board
GND: RN1.1 (common), U5.8 (GND), U6.10 (GND); also elsewhere on the board
unnamed: RN1.2 (R1), SW2.16, U6.2 (A0)
unnamed: RN1.4 (R3), SW2.14, U6.4 (A2)
unnamed: RN1.5 (R4), SW2.13, U6.5 (A3)
unnamed: RN1.6 (R5), SW2.12, U6.6 (A4)
unnamed: RN1.7 (R6), SW2.11, U6.7 (A5)
unnamed: RN1.8 (R7), SW2.10, U6.8 (A6)
unnamed: RN1.9 (R8), SW2.9, U6.9 (A7)
unnamed: SW1.1, U5.15 (O0)
unnamed: SW1.2, U5.14 (O1)
unnamed: SW1.3, U5.13 (O2)
unnamed: SW1.4, U5.12 (O3)
unnamed: SW1.5, U5.11 (O4)
unnamed: SW1.6, U5.10 (O5)
unnamed: SW1.7, U5.9 (O6)
unnamed: SW1.8, U5.7 (O7)

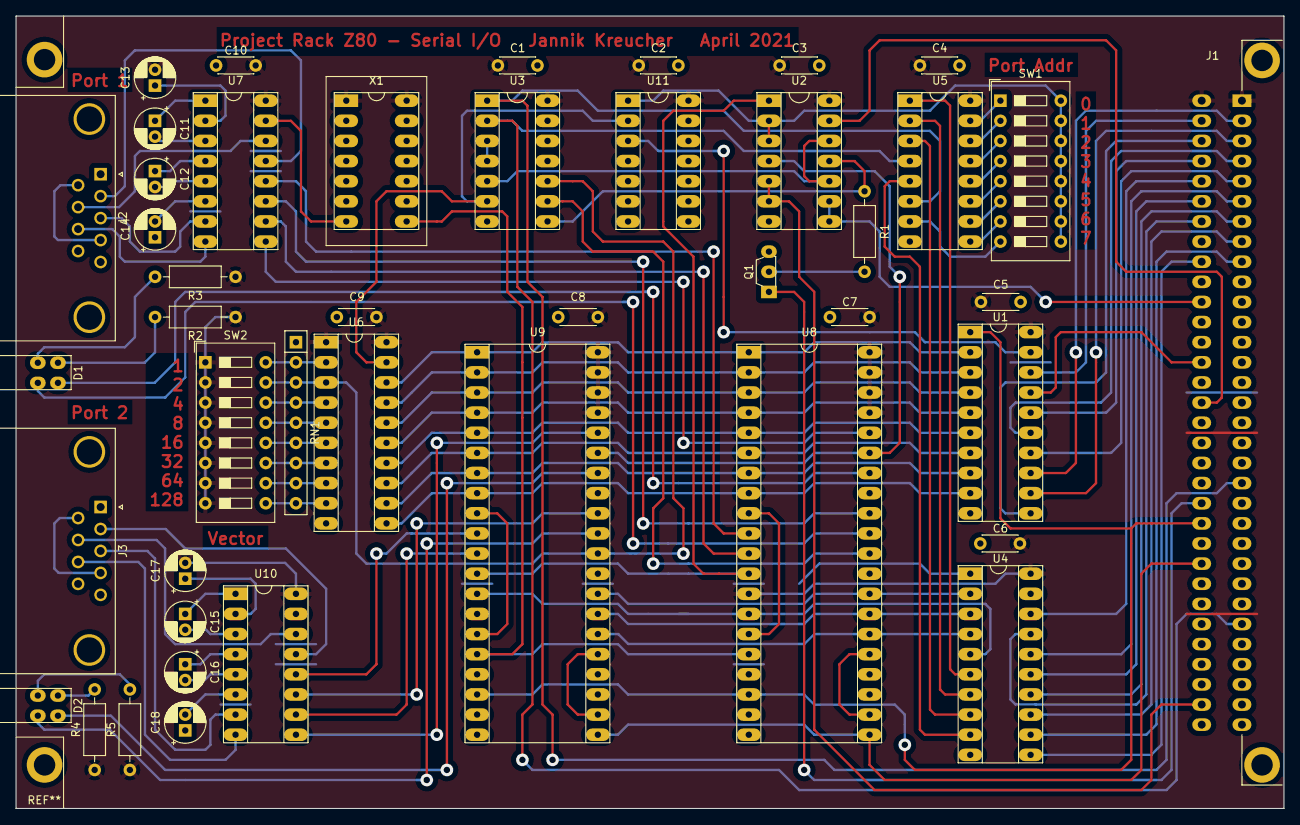
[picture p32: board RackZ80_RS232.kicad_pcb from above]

Board: 2 copper layers, 160.0 x 100.0 mm, 44 parts (0 on the bottom side), 109 nets.

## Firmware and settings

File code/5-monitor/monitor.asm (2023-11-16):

; defines
PORT_MEMPAGE	.equ	0x00
PORT_UART1		.equ	0x10
PORT_UART2		.equ	0x18
; variables
PTR_INPUT		.equ	0x8000
PTR_ARGV		.equ	0x8020 ; list of pointers to PTR_INPUT
PTR_ARGC		.equ	0x8030


.org 0x0000
init:
	di
	; set upper ram page
	;ld a, 0x00
	;out (PORT_MEMPAGE), a
	; cpu init
	ld sp, 0xFFFF
	ld a, 0x00
	ld i, a
	im 2
	; device init
	call uart_init

	; clear memory
	ld hl, 0x8000
_init_loop:
	ld (hl), 0xFF
	inc hl
	ld a, h
	cp 0xFF
	jp nz, _init_loop

	; jump to main
	jp main



.org 0x0100
main:
	ld hl, str_hello
	call uart1_puts
_main_loop:
	; print promt
	ld hl, str_promt
	call uart1_puts
	; input buffer
	ld hl, PTR_INPUT
	; pointer to argument
	ld bc, hl
	; argc
	ld a, 0
	ld (PTR_ARGC), a
_main_loop_getc:
	call uart1_getch
	; check if newline or space
	cp 0x0D
	jr z, _main_newline
	; echo back
	call uart1_putc
	; check if space
	cp ' '
	jr nz, _main_loop_no_space
	; save memory location to argv pointer
	call add_argv
	; save next location as start of new argument
	ld bc, hl
	inc bc
	; save a 0 instead of a space
	ld a, 0
_main_loop_no_space:
	; check if backspace
	cp 0x08
	jr z, _main_loop_backspace
	; not return: put into buffer
	ld (hl), a
	inc hl
	jr _main_loop_getc
_main_loop_backspace:
	ld a, 0
	ld (hl), a
	; check if pointer at 0
	ld de, PTR_INPUT
	sbc hl, de
	add hl, de
	jp z, _main_loop_getc
	; if there are some chars, delete last one
	dec hl
	; print space
	ld a, ' '
	call uart1_putc
	ld a, 0x08
	call uart1_putc
	jr _main_loop_getc
_main_newline:
	; enter pressed
	; end buffer with terminating 0
	ld (hl), 0x00
	; save last argument in argv list
	call add_argv
	; parse command
	call uart1_newline
	call handle_cmd
	; print shell again
	jp _main_loop



; add_argv
;   add pointer in bc to argv list
add_argv:
	push de
	push hl
	; get argc and multiply by 2
	ld a, (PTR_ARGC)
	sla a
	ld d, 0
	ld e, a
	; de is offset
	ld hl, PTR_ARGV
	add hl, de
	ld (hl), bc
	; increment argc
	ld a, (PTR_ARGC)
	inc a
	ld (PTR_ARGC), a
	; return
	pop hl
	pop de
	ret



; handle command string
;   command string in argv
handle_cmd:
	; check if input buffer zero
	ld a, (PTR_INPUT)
	cp 0
	ret z
	; get mnemonic id by comparing to list
	ld bc, (PTR_ARGV)
	ld hl, lst_cmds_str_ptr
	call get_index
	cp 0xFF
	jr z, _handle_cmd_error
	; get function pointer, index in a
	ld hl, lst_cmds_ptr
	call get_word_from_index
	push hl
	; save return address in stack for return
	call _handle_cmd_call_func
_handle_cmd_call_func:
	; get pc address 0x0178
	pop hl
	ld bc, 8
	add hl, bc
	push hl ; hl points to address after jp (hl)
	; call address in hl
	pop hl
	jp (hl)
	ret
_handle_cmd_error:
	ld hl, str_error
	call uart1_puts
	ret



; pointer to string in bc
; pointer to list of strings in hl
; 
;   compares command to first space to list of commands
get_index:
	; save start of string
	ld a, 0
	push af
	ld de, bc
_get_index_list_loop:
	; get pointer to string by index
	ld hl, lst_cmds_str_ptr
	call get_word_from_index ; gets pointer to string with index a
	; last index is zero
	ld bc, 0x0000
	sbc hl, bc
	add hl, bc
	jr z, _get_index_not_found
	; get start of string, array pointer in hl
	ld bc, de
	; pointer to command_str[a] in hl
	; compare strcmp(command_str[a], str)
	call strcmp
	; check if strings were the same
	cp 1
	jr z, _get_index_found
	; not equal: next index
	pop af
	inc a
	push af
	; index in a
	jr _get_index_list_loop
_get_index_found:
	pop af
	ret
_get_index_not_found:
	pop af
	ld a, 0xFF
	ret



; get_word_from_index
;   hl - pointer to start of list
;    a - index of list of words
;   Returns: hl - word at (hl + a*2)
get_word_from_index: ; hl = (hl+a*2)
	push af
	sla a ; a=a*2
	; add a to hl
	add a, l
	ld l, a
	adc a, h
	sub l
	ld h, a
	; get word from pointer
	push bc
	ld bc, hl
	ld a, (bc)
	ld l, a
	inc bc
	ld a, (bc)
	ld h, a
	pop bc
	; return
	pop af
	ret



; strcmp
;   compare two strings
;   hl - first string
;   bc - second string
;   returns a: 0 not equal, 1 equal
strcmp:
	; check if second string ends
	ld a, (hl)
	cp 0
	jr z, _strcmp_equal
	; check if first string ends
	ld a, (bc)
	cp 0
	jr z, _strcmp_equal
	; check if chars are the same
	cp (hl)
	jr nz, _strcmp_not_equal
	; next char
	inc hl
	inc bc
	jr strcmp
_strcmp_not_equal:
	ld a, 0
	ret
_strcmp_equal:
	ld a, 1
	ret



; command: print help
cmd_help:
	ld hl, str_cmd_help
	call uart1_puts
	; index counter
	ld b, 0
_cmd_help_loop:
	ld a, b
	ld hl, lst_cmds_str_ptr
	call get_word_from_index
	; check if pointer is zero
	ld de, 0x0000
	sbc hl, de
	add hl, de
	ret z
	; print command name
	call uart1_puts
	; print space
	ld a, ' '
	call uart1_putc
	call uart1_putc
	; print description
	inc hl
	call uart1_puts
	call uart1_newline
	; next index
	inc b
	jr _cmd_help_loop
str_cmd_help: .db "Commands:", 0x0D, 0x0A, 0x00



; command: dump memory
;   starting address in hl
;   puts first argument in bc, second in de
cmd_dump:
	ld a, (PTR_ARGC)
	cp 3
	jr nz, _cmd_dump_error
	; get second argument
	ld hl, PTR_ARGV
	ld a, 1
	call get_word_from_index
	; convert string to hex word
	call word_to_val
	push bc
	; get third argument
	ld hl, PTR_ARGV
	ld a, 2
	call get_word_from_index
	; convert string to hex word
	call word_to_val
	; dump memory (start in hl, end in bc)
	pop hl
	call dump
	call uart1_newline
	ret
_cmd_dump_error
	ld hl, str_cmd_dump_help
	call uart1_puts
	ret
str_cmd_dump_help: .db "Usage: dump <start_addr> <end_addr>", 0x0D, 0x0A, "address in hex", 0x0D, 0x0A, "example: dump 1000", 0x0D, 0x0A, 0x00



; command: write memory
;   argv in PTR_ARGV
;   argc in PTR_ARGC
cmd_mset:
	ld a, (PTR_ARGC)
	cp 2
	jr nz, _cmd_mset_error
	; get second argument
	ld hl, PTR_ARGV
	ld a, 1
	call get_word_from_index
	; convert argument to word
	call word_to_val
	ld hl, bc
	; wait for data and copy to location
_cmd_mset_upper:
	; get first char
	call uart1_getch
	call ch_to_upper
	; return on newline
	cp 0x0D
	jr z, _cmd_mset_end
	; convert to 4 bits and shift
	call nibble_to_val
	rrca
	rrca
	rrca
	rrca
	ld b, a
	; get lower nibble
	call uart1_getch
	call ch_to_upper
	; return on newline
	cp 0x0D
	jr z, _cmd_mset_end
	; convert to 4 bits
	call nibble_to_val
	or b
	; save to memory
	ld (hl), a
	; next memory location
	inc hl
	jr _cmd_mset_upper
_cmd_mset_end:
	call uart1_newline
	ret
_cmd_mset_error:
	ret



; command: jump to location
;   argv in PTR_ARGV
;   argc in PTR_ARGC
cmd_jump:
	ld a, (PTR_ARGC)
	cp 2
	jr nz, _cmd_jump_error
	; get second argument
	ld hl, PTR_ARGV
	ld a, 1
	call get_word_from_index
	; convert argument to word
	call word_to_val
	ld hl, bc
	; jump to location
	jp (hl)
_cmd_jump_error:
	ret



; command: change upper ram page
cmd_page:
	ld a, (PTR_ARGC)
	cp 2
	jr nz, _cmd_mset_error
	; get second argument
	ld hl, PTR_ARGV
	ld a, 1
	call get_word_from_index
	; convert argument to word
	call word_to_val
	ld a, c
	; write page id
	out (PORT_MEMPAGE), a
	ret
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

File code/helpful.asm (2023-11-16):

; my own reference for useful z80 code


; cp
cp arg1
; arg1 >  a -> carry set
; arg1 <= a -> carry reset
; arg1 == a -> zero set
; arg1 != a -> zero reset
;
; a <  arg1 -> carry set
; a >= arg1 -> carry reset


; ch_to_upper
;   char in A, convert to uppercase
ch_to_upper:
	; less than 'a': return
	cp 'a'
	ret c
	; greater than 'z': return
	cp 'z'+1
	ret nc
	; convert to upper case
	sub 0x20
	ret


; nibble_to_val
;   char in A, convert to value
nibble_to_val:
	cp '9'+1              ; is it a digit?
	jr c, nibble_to_val_1 ; jump if number
	sub 7                 ; for A-F
nibble_to_val_1:
	sub '0'
	and 0x0F              ; lower nibble only
	ret


; val_to_nibble
;   value in A, convert to hex nibble in ascii
val_to_nibble:
	and 0x0F
	add a, '0'
	cp '9'+1
	jr c, val_to_nibble_1 ; jump if less
	add a, 'A'-'0'-0xA
val_to_nibble_1:
	ret


; print_nibble
;   byte in A, convert to char and print via uart
print_nibble:
	and 0x0F
	add a, '0'
	cp '9'+1
	jr c, print_nibble_1
	add a, 'A'-'0'-0xA
print_nibble_1:
	call uart1_putc
	ret
; print_byte
;   byte in A
print_byte:
	push af
	rrca
	rrca
	rrca
	rrca
	call print_nibble
	pop af
	call print_nibble
	ret



dump_mem:
	push af
	push bc
	ld b, 0x00
dump_mem_loop:
	; check if newline needed
	ld a, l
	and 0x0F
	jr nz, dump_mem_1 ; skip newline
	call uart1_newline
	; print address
	ld a, h
	call print_byte
	ld a, l
	call print_byte
	ld a, ':'
	call uart1_putc
	ld a, ' '
	call uart1_putc
dump_mem_1:
	; print byte
	ld a, (hl)
	call print_byte
	ld a, ' '
	call uart1_putc
	; address counter
	inc hl
	; byte counter
	dec b
	jr nz, dump_mem_loop
	pop bc
	pop af
	ret

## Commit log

2021-03-08 processor schematic 3d models
    [Fischer_4TE.step, RackZ80_Processor.kicad_pcb, Subrack4TE_FrontPanel.FCStd]
2021-03-14 Breadboard Prototype
    [RackZ80_Processor.kicad_pcb, breadboard_z80_processor.kicad_pcb, breadboard_z80_processor.sch]
2021-04-16 schematics update
    [DIN41612_H15.step, Fischer_4TE.step, Fischer_8TE.step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]
2023-11-04 uart demo code fixed
    [uart_echo.asm]
2023-11-05 migrated kicad 5 to kicad 7
    [MemoryLogic.kicad_sch, Power.kicad_sch, RackZ80_Backplane.kicad_pcb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]
2023-11-14 simple monitor code and power supply module
    [BlockTrafo_VC10_10VA.step, DIN41612_H15_Male_90deg_ept.step, Fischer_4TE.step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]
